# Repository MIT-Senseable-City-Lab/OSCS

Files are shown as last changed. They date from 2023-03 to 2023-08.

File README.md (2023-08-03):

# FLATBURN: the open source city scanner

[Project website](https://senseable.mit.edu/flatburn).

### Flatburn Overview
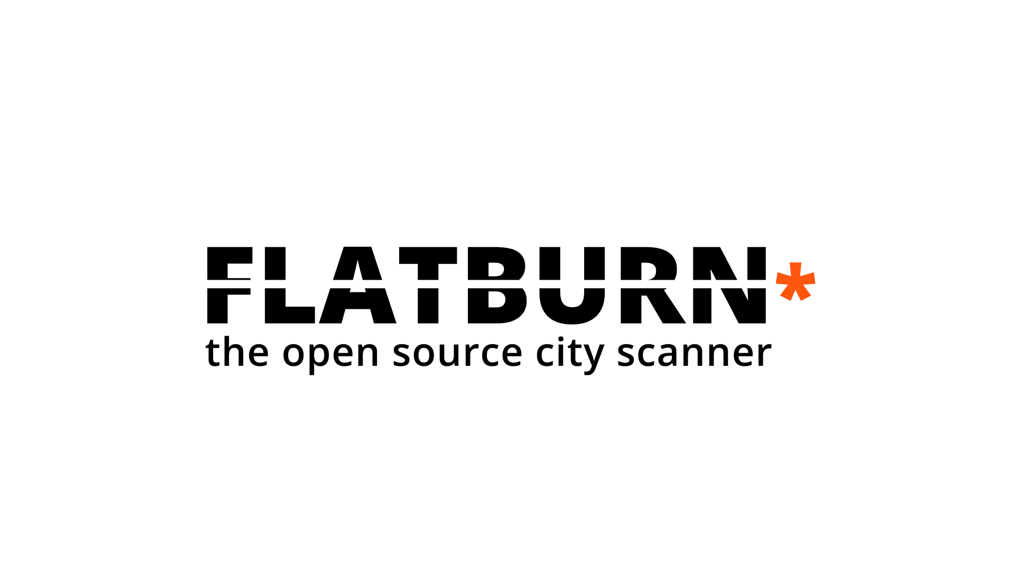
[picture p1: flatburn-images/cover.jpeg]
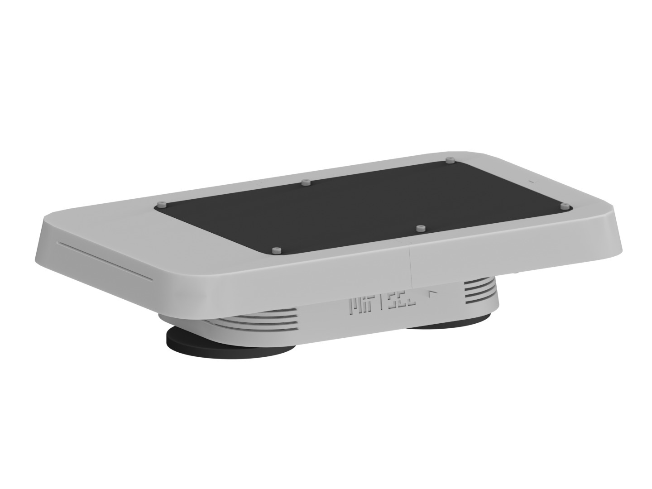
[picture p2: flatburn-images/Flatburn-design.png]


Part of the [City Scanner](https://senseable.mit.edu/cityscanner/) project at [MIT Senseable City Lab](https://senseable.mit.edu), Flatburn is an open-source, solar-powered, modular sensing platform that can be easily deployed on road vehicles to collect various environmental data. 

This repository contains all information to [build](https://github.com/MIT-Senseable-City-Lab/OSCS/tree/main/Build) your own Flatburn, [explore](https://github.com/MIT-Senseable-City-Lab/OSCS/tree/main/Explore) datasets collected using Flatburn and other City Scanner deployments worldwide and [learn](https://github.com/MIT-Senseable-City-Lab/OSCS/tree/main/Learn) how to perform environmental analysis and use the data to contribute to the development of healtier cities.

## Build
 - [/hardware](Build/Hardware)  
    - [fabrication files](Build/Hardware/Hardware%20enclosure) for Flatburn mechanical parts, including files for [3D printing](Build/Hardware/Hardware%20enclosure/To%20Print), [laser cutting](Build/Hardware/Hardware%20enclosure/To%20lasercut), and a [CAD model](Build/Hardware/Hardware%20enclosure/Flatburn_assembly.step) of the full assembly. A [bill of materials](https://docs.google.com/spreadsheets/d/1qiVyINNuo0XEu6MasEJE_p4onlJh241j/edit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) listing all the required mechanical components is also included.
    - [hardware schematics](Build/Hardware/Hardware%20schematics) contains `.brb` files for the main-board and the sensor-board which can be viewed using the [Cadence](https://www.cadence.com/en_US/home/tools/pcb-design-and-analysis/allegro-downloads-start.html) free viewer, schematics of the PCB in `.pdf` format, and a [bill of materials](https://docs.google.com/spreadsheets/d/1-UVIJEneydIf8kLRng4QxvzjM4k2ZoDa/edit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) for the electronics components.
 - [/firmware](Build/Firmware): The Flatburn main firmware code base, developed using [Particle.io](https://www.particle.io/workbench/) workbench.
 - [/fabrication handbook](Build/Handbook): The assembly guide with detailed instructions on how to build flatburn.

## Explore
- [/datasets](Explore/Datasets): `.csv` calibrated air quality datasets collected during City Scanner deployments worldwide. 
- [/calibration handbook](Explore/Calibration%20Handbook): a guide for validation and calibration of the data collected by Flatburn.

## Learn
- [/coding exercise](Learn/Coding%20Exercise): [jupyter](https://jupyter.org/) notebooks for a Python coding activity to introduce non-experts to air quality and environmental sensing and analysis methods. The activity includes exploring time series analysis, geospatial analysis, and pollution hotspot analysis. The conding activity can be used with the [datasets](Explore/Datasets) captured by previous City Scanner deployment as well as data captured by Flatburn.
- [/facilitator handbook](Learn/Facilitator%20Handbook): a facilitator guide and educational slides to implement the coding exercise as part of workshops or classroom activities.

All materials are released under [MIT license](LICENSE).

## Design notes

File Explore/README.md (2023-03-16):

# EXPLORE OSCS
The Explore folder contains two sections:
- [/datasets](https://github.com/MIT-Senseable-City-Lab/OSCS/tree/main/Explore/Datasets): The folder contains `.csv` Calibrated air quality data of City Scanner. 
- [/data collection document](https://github.com/MIT-Senseable-City-Lab/OSCS/tree/main/Explore/Calibration%20Handbook): Open-source manual and code for data collection

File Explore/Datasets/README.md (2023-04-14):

# Open City Scanner Data
This folder contains open City Scanner data sets collected in four deployments in three cities. Raw sensor readings were collected and calibrated following standardized air sensor performance evaluation guidelines recommended by the U.S. EPA. The general method is presented in the following diagram and details can be found in the open source [calibration handbook](https://github.com/MIT-Senseable-City-Lab/OSCS/blob/main/Explore/Calibration%20Handbook/Calibration%20Handbook.pdf).



Figure. Data post-processing and validation protocols

Detailed information about the deployments and data files is included in he following table. In total, there are eight data files. Given that the second pilot in NYC contains a huge amount of data, its full dataset is divided into five sections. A [data descriptor](https://github.com/MIT-Senseable-City-Lab/OSCS/blob/main/Explore/Datasets/OSCS_OpenDataSupplement.pdf) is also included. 

Table. Deployments and open data sets
|City|Sensing target pollutants|Sensing fleet|Duration|
|----|---|---|---|
|New York City, US|Particulate matter, particle size distribution, NO2|Five municipal vehicles|Jan. 2020 - Feb. 2020; Sep. 2021 - Dec. 2021|
|Boston, US|Particulate matter, particle size distribution, NO2|One mobile air laboratory|Feb. 2022 - Apr. 2022|
|Beirut, Lebanon|Particulate matter, particle size distribution|Two taxis|Feb. 2022 - Jun. 2022|

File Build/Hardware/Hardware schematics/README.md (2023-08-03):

Files for Electronic production

A BoM (bill of materials) listing all the required parts and components to build a Flatburn hardware can be found [here](https://docs.google.com/spreadsheets/d/1-UVIJEneydIf8kLRng4QxvzjM4k2ZoDa/edit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)

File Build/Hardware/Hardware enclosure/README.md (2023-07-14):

Files for 3D printing, laser-cutting and the full CAD assembly.

A BoM (bill of materials) listing all the required parts and components to build a Flatburn enclosure is available [here](https://docs.google.com/spreadsheets/d/1qiVyINNuo0XEu6MasEJE_p4onlJh241j/edit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).

**Process pictures showing the main assembly steps:**



Our prototypes were printed on a Flashforge Guider ii, but the files can be printed on most standard desktop 3D printers (e.g. Prusa i3, Ender 3, Ultimaker etc). 

We suggest the following settings:

* Infill type: Triangular or Esagonal 
* Infill Percentage: at leat 50% 
* Layer height: this depend on the printer nozzle, I would go with the pre-defined setting.

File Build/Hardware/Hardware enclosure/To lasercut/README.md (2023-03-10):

Vector `.dxf` files for lasercutting of the enclosure 'base-plate' and 'in-between plate' (dimensions in mm). Suggested material is acrylic with the relevant material thickness specified in the name (closest available metric values can also be substituted :) ). The 'in-between' plate may alternatively also be [3D printed](https://github.com/MIT-Senseable-City-Lab/OSCS/tree/main/Build/Hardware/Hardware%20enclosure/To%20Print).

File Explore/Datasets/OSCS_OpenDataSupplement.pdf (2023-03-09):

## City Scanner Open Data Supplement

This document provides expanded definitions, units, and more information on the data provided in the .CSV files from City Scanner deployments.

### Data Fields

time

- The time field is in Unix time and can be converted to local time with a simple script or using online tools.

latitude, longitude

- The latitude and longitude readings from the devices are determined via GPS and given in degrees for projected corrdinates.

pm1, pm25, pm10

- The particulate matter (pm) readings from the optical particle counter after calibration.
- The units for each are instantaneous mass concentrations in µg/m³

no2

- The nitrogen dioxide (no2) readings from the gas sensors after conversion and calibration.
- The unit is instantaneous concentrations in parts per billion (ppb).

bin0-bin23

- Twenty-four bins from the OPC containing particle number counts for different sizes, ranging from 0.35 to 40 µm. The bin boundary sizes are as follows from bin0 to bin23:
- 0.35
- 0.46
- 0.66
- 1.0
- 1.3
- 1.7
- 2.3
- 3.0
- 4.0
- 5.2
- 6.5

- 8.0
- 10.0
- 12.0
- 14.0
- 16.0
- 18.0
- 20.0
- 22.0
- 25.0
- 28.0
- 31.0
- 34.0
- 37.0
- 40.0

temperature

- Ambient temperature reading in degrees Celsius.

humidity

- Ambient relative humidity reading in percentage

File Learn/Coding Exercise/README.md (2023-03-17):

This folder contains a coding activity written in Python to introduce users to air quality and environmental sensing methods
by working with CityScanner Data, exploring time series analysis, geospatial analysis, and pollution hotspot analysis.
There are 2 versions: 
- One is a `.ipynb` file containing python code and some descriptive text, which can be run in an environment of your choosing.
- The other is a `.ipynb` file intended to be run on the [Google CoLab](https://colab.research.google.com/) platform. 

The notebooks provide sample code to run with New York City Deployment data, which can be edited to use different data files we provide in [explore/datasets](/Explore/Datasets).

Please refer to the [facilitator handbook](/Learn/Facilitator%20Handbook) for further instructions.

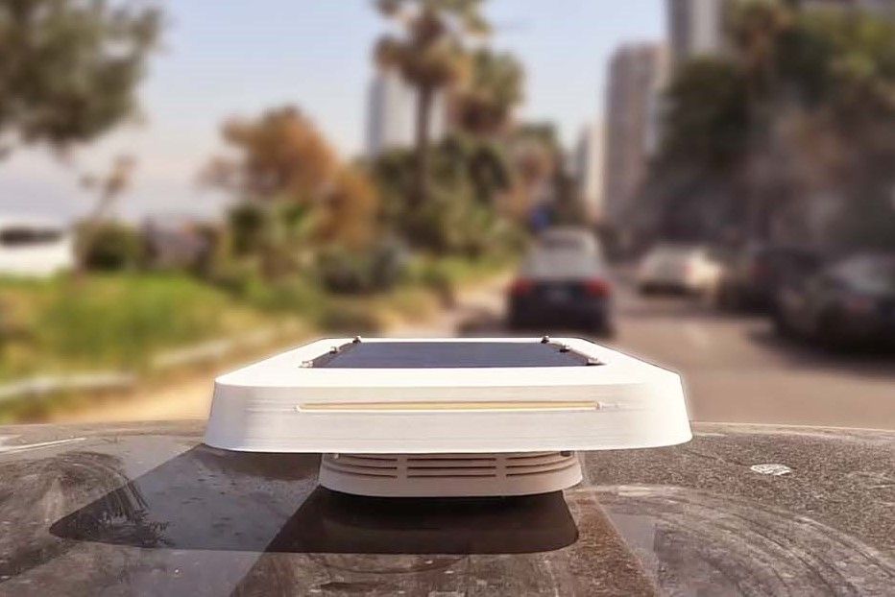
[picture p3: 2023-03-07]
flatburn-images/Flatburn.jpeg

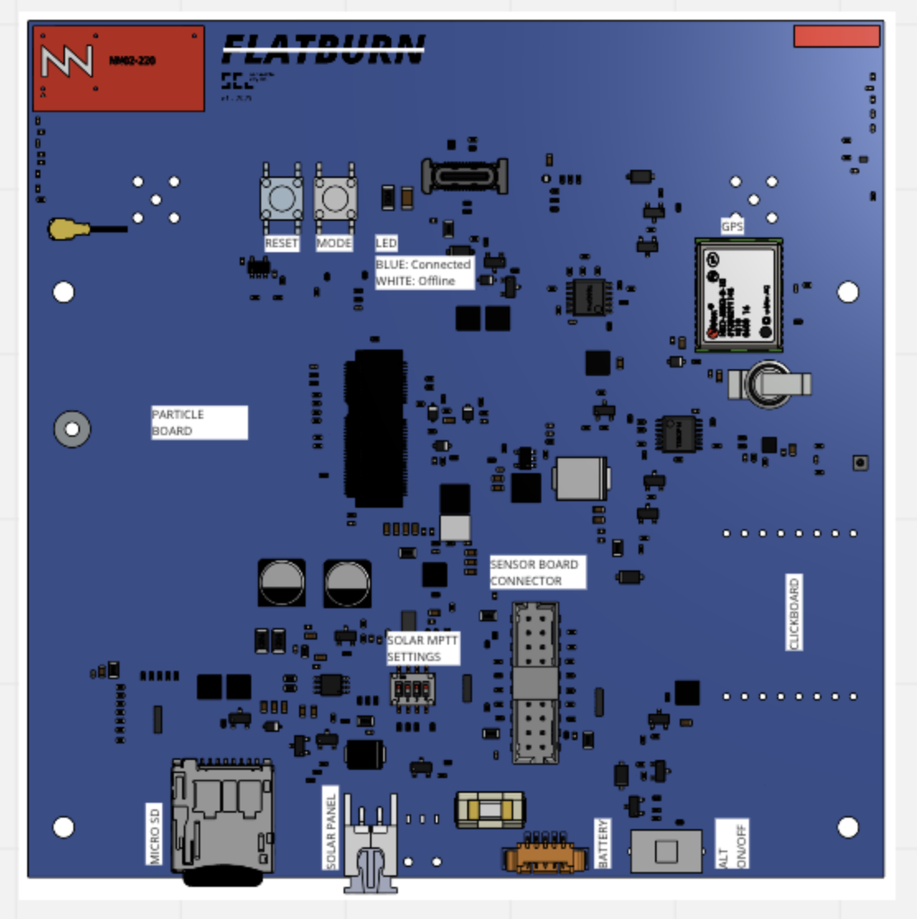
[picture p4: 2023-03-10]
flatburn-images/Mainboard.png

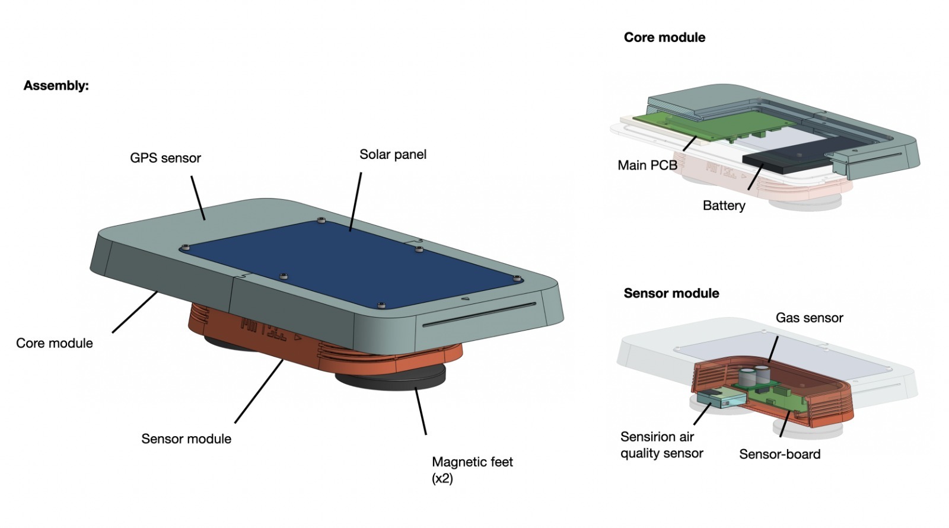
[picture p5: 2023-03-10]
flatburn-images/flatburn configuration.jpeg

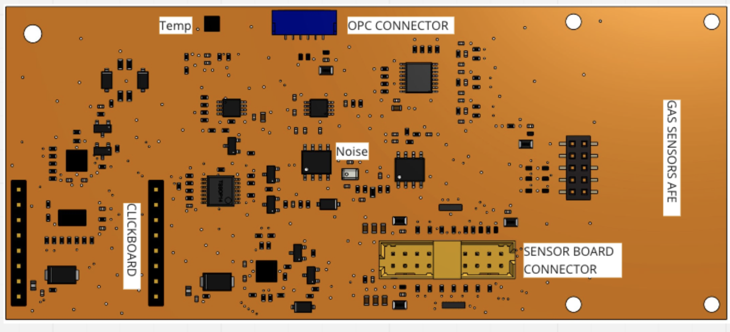
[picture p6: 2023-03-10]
flatburn-images/Sensorboard.png

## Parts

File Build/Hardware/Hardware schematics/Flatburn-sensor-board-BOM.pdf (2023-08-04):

Item | Quantity | Reference | Part | MPN | MPN2 | Description | Temperature | Distributor | Type | Package | Database
1 | 1 | CS1 | CS V2 2L 35um | | | C.S. CS SENSOR V2 (115x52)mm HAL 2L/SO/SR sp=1.6mm Cu=35um | TG140 | WE-ONLINE
2 | 36 | C9,C10,C11,C15,C16,C17,C18,C19,C20,C27,C28 ,C99,C102,C103,C104,C105,C106,C108,C109,C1 10,C111,C112,C113,C114,C115,C116,C117,C123 ,C124,C125,C126,C128,C129,C130,C132,C133 | 100n/50V | | | CHIP CAP.CER. 100nF 50V 10% X7R 0402 | -55..+125 | | SMD | CS-C-0402
3 | 8 | C21,C22,C23,C24,C25,C26,C107,C134 | 10u/10V-X5R | | | CHIP CAP.CER. 10uF 10V 10% X5R 0603 | | FAE | SMD | CS-C-0603 | 28168
4 | 4 | C121,C122,C127,C131 | 1u/16V-X5R | | | CHIP CAP.CER. 1uF 16V 10% X5R 0402 | | FAE | SMD | CS-C-0402 | 37485
5 | 2 | DZ3,DZ5 | MMSZ5226BT1G | MMSZ5226BT1G | | DIODO ZENER 0.5W 3.3V MMSZ5226BT1G ONSEMI SOD123 SMT | | M-863-MMSZ5226BT1G | SMD | SOD123
6 | 2 | DZ4,DZ7 | MMSZ5221BT1G | MMSZ5221BT1G | | DIODO ZENER 0.5W 2.4V MMSZ5221BT1G ONSEMI SOD123 SMT | -55°C .. +150°C | M-863-MMSZ5221BT1G | SMD | SOD123
7 | 2 | F2,F3 | 0ZCM0020FF2G | 0ZCM0020FF2G | | FUSIBILE RIPRIST. 0.2A 9V 0603 0ZCM0020FF2G BEL FUSE SMT | -40°..+85° | FAE | SMD | FS-0603 | 40877
8 | 1 | J7 | 878322014 | 878322014 | | HEADER 20P M DOPPIA FILA P=2.00 878322014 MOLEX SMD | -55..105 | M-538-87832-2014 | SMD | J-10X2-0200-MDS-878322014
9 | 2 | J9,J10 | STRIP 8P - FDT | | | STRIP 1P F/D P=2.54 H=7 NERA 801-87-036-1001 | | FAE | THT | J-8-0254-FDT | 1692
10 | 1 | J11 | BF100-10-A-D-1-0640-L-C | BF100-10-A-D-1-0640-L-C | | CONN. F-C 10P F/D P=2 BF100-10-A-D-1-0640-L-C GCT SMT | | D-2073-BF100-10-A-D-1-0640-L-CCT-ND | SMD | J-5X2-0200-FDS-BF100
11 | 1 | J12 | SM06B-GHS-TB | SM06B-GHS-TB | | CONN. GH 6P M/O P=1.25 GH JST SM06B-GHS-TB(LF)(SN) | -25°..+85° | D-455-1568-1-ND | SMD | J-6-0125-MOS-SM06B-GHS-TB
12 | 1 | J13 | S5B-ZR-SM4A-TF | S5B-ZR-SM4A-TF | | CONN. ZH 5P M/O P=1.5 ZH JST S5B-ZR-SM4A-TF | -25°..+85° | D-455-1696-1-ND | SMD | J-5-0150-MOS-S5B-ZR-SM4A
13 | 5 | L3,L5,L6,L7,L8 | BLM21PG221SN1D | BLM21PG221SN1D | | FILTRO 220R 2A 25% 0805 BLM21PG221SN1D MURATA SMT | -55°..+125° | FAE | SMD | LS-0805 | 20590
14 | 3 | Q11,Q24,Q26 | BSS84 | | | TRANSISTOR MOSFET P BSS84,215 SOT-23 SMT | -55°..+150° | FAE | SMD | SOT23 | 28241
15 | 3 | Q12,Q25,Q27 | BC817-25 | | | TRANSISTOR NPN BC817-25 SOT-23 SMT | | FAE | SMD | SOT23 | 15414
16 | 1 | Q28 | BSS138 | | | TRANSISTOR MOSFET N BSS138 SOT-23 SMT | | FAE | SMD | SOT23 | 17269
17 | 29 | R18,R19,R20,R21,R22,R23,R24,R25,R26,R27,R2 8,R29,R32,R36,R40,R41,R42,R43,R44,R45,R46, R47,R50,R96,R97,R101,R102,R226,R231 | 33R | | | CHIP RES. 33R 0402 1/16W 1% 100PPM/°C | | FAE | SMD | RS-0402 | 38764
18 | 2 | R34,R48 | 0R | | | CHIP RES. 0R 0603 1/16W 1% | -55°..+150° | FAE | SMD | RS-0603 | 15541
19 | 5 | R35,R61,R62,R249,R288 | 0R | | | CHIP RES. 0R 0402 1/16W 1% | | FAE | SMD | RS-0402 | 25681
20 | 15 | R37,R57,R232,R236,R239,R240,R241,R242,R24 4,R246,R270,R271,R276,R289,R290 | 100k | | | CHIP RES. 100K 0402 1/16W 1% | | FAE | SMD | RS-0402 | 25127
21 | 4 | R51,R234,R245,R282 | 1k | | | CHIP RES. 1K 0402 1/16W 1% | -55°..+155° | FAE | SMD | RS-0402 | 25126
22 | 6 | R53,R54,R105,R225,R230,R280 | 100R | | | CHIP RES. 100R 0402 1/16W 1% | | FAE | SMD | RS-0402 | 26315
23 | 22 | R59,R60,R106,R233,R235,R237,R238,R247,R25 2,R253,R256,R257,R258,R263,R264,R265,R266, R272,R274,R278,R281,R284 | 10k | | | CHIP RES. 10K 0402 1/16W 1% | -55°..+125° | FAE | SMD | RS-0402 | 25129
24 | 6 | R254,R255,R259,R260,R261,R262 | 5.1k | | | CHIP RES. 5K1 0402 1/16W 1% | -55°..+155° | FAE | SMD | RS-0402 | 46041
25 | 2 | R267,R268 | 1M | | | CHIP RES. 1M 0402 1/16W 1% | | FAE | SMD | RS-0402 | 32464
26 | 1 | R269 | 390R | | | CHIP RES. 390R 0603 1/16W 1% | | FAE | SMD | RS-0603 | 20433
27 | 2 | R273,R275 | 120k | RC0402FR-07120KL | | CHIP RES. 120k 0402 1/16W 1% 100PPM/C | | | SMD | RS-0402
28 | 1 | R283 | 2.2k | | | CHIP RES. 2K2 0402 1/16W 1% | | FAE | SMD | RS-0402 | 35095
29 | 2 | TVS7,TVS11 | D3V3F8U9LP3810-7 | | | INTEGRATO SIGNAL PROTECTION D3V3F8U9LP3810-7 DIODES UDFN3810-9 SMT | -55°..+85° | M-621-D3V3F8U9LP3810-7 | SMD | UDFN3810-9
30 | 13 | TVS8,TVS9,TVS10,TVS13,TVS14,TVS15,TVS16 ,TVS17,TVS18,TVS19,TVS20,TVS21,TVS22 | NSPU3051N2T5G | | | DIODO TVS TRANSIL UNIDIR. 5.5V NSPU3051N2T5G X2DFN SMT | -65°..+150° | D-NSPU3051N2T5GOSC T-ND | SMD | D-XDFN2
31 | 2 | U1,U3 | TXS0104ERGYR | TXS0104ERGYR | | INTEGRATO TXS0104ERGYR TEXAS VQFN14 SMT | -40°C..85°C | FAE | SMD | VFQFN14-EXP-0350X0350 | 41323
32 | 1 | U2 | TXS0108ERGYR | TXS0108ERGYR | | INTEGRATO TXS0108ERGYR TI VQFN20 SMT | -40°..85° | D-296-24806-1-ND | SMD | VFQFN20-EXP-0350X0450
33 | 1 | U15 | 74LV4066PW | 74LV4066PW | | INTEGRATO SWITCH 74LV4066PW NXP TSSOP14 SMT | -40°C..125°C | M-771-LV4066PW118 | SMD | TSSOP14
34 | 1 | U16 | BME280 | BME280 | | INTEGRATO BME280 BOSCH LGA8 SMT | -40°..+85° | FAE | SMD | IC-BME280 | 38357
35 | 1 | U17 | ADS7828E | ADS7828E | ADS7828EB | INTEGRATO ADC/DAC ADS7828E TEXAS TSSOP16 SMT | -40°..+85° | FAE | SMD | TSSOP16 | 26248
36 | 1 | U18 | CMM-2718AT-42316-TR | CMM-2718AT-42316-TR | | MICROPHONE MEMS CUI DEVICES SMT | -40°..+100° | M-490-CMM2718AT42316TR | SMD | lga4-0275x0185
37 | 1 | U19 | LTC1966IMS8 | LTC1966IMS8#PBF | | INTEGRATO RMS-TO-DC LTC1966 LINEAR MSOP8 SMT | -40°..+85° | M-584-LTC1966IMS8#PBF | SMD | MSOP8
38 | 2 | U20,U21 | MCP6022-I/SN | MCP6022-I/SN | | INTEGRATO SIGNAL AMPLIFIER MCP6022-I/SN MICROCHIP SOIC-8 SMT | -40°..+85° | M-579-MCP6022-I/SN | SMD | SOIC8
39 | 1 | U22 | MAX5805BAUB+T | MAX5805BAUB+T | | INTEGRATO DAC MAX5805BAUB+ MAXIM MSOP10 SMT | -40°..+125° | M-700-MAX5805BAUB+T | SMD | MSOP10
194 | 17

# MECHANICAL

1 | 1 | ASS1 | SEN55-SDN-T | SEN55-SDN-T | SENSORE PM SEN55-SDN-T SENSIRION | -10°..50° | M-403-SEN55-SDN-T | THT
2 | 1 | ASS2 | 810-0021-01 | 810-0021-01 | SENSORE NO2/O3/NO 810-0021-01 ALPHASENSE | -10°..50° | | THT
2 | 2

# NOT MOUNTED

1 | 1 | ASS3 | NU | SPS30 | SENSORE PM SPS30 SENSIRION | -10°..60° | M-403-SPS30 | THT
2 | 1 | C14 | NU | | CHIP CAP.CER. 1nF 50V 10% X7R 0402 | | FAE | SMD | CS-C-0402 | 33357
3 | 2 | C100,C101 | NU | | CHIP CAP.CER. 100nF 50V 10% X7R 0402 | -55..+125 | | SMD | CS-C-0402
4 | 2 | DS5,DS6 | NU | SS14 | DIODO SCHOTTKY 1A 40V SS14 SMA SMT | | FAE | SMD | SMA | 16655
5 | 3 | FID1,FID2,FID3 | TPS | | FIDUCIAL | | FAE | SMD | FIDUCIAL
6 | 2 | R33,R49 | NU | | CHIP RES. 0R 0603 1/16W 1% | -55°..+150° | FAE | SMD | RS-0603 | 15541
7 | 5 | R38,R228,R243,R286,R287 | NU | | CHIP RES. 0R 0402 1/16W 1% | | FAE | SMD | RS-0402 | 25681
8 | 1 | R39 | NU | | CHIP RES. 33R 0402 1/16W 1% 100PPM/°C | | FAE | SMD | RS-0402 | 38764
9 | 5 | R248,R250,R251,R277,R285 | NU | | CHIP RES. 10K 0402 1/16W 1% | -55°..+125° | FAE | SMD | RS-0402 | 25129
CUSTOMER | MIT
PROJECT | 2022-0630 (CITYSCANNER-EVO-SENSOR)
REVISION | 2
SCHEMATIC | 20220630_CITYSCANNER-EVO-SENSOR_V2
DATA | 23/05/2023
DRAFTED | M.
APPROVED | Nome Approved

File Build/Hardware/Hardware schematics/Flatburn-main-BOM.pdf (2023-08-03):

Item | Quantity | Reference | Part | MPN | Description | Temperature | Distributor | Type | Package | Database
1 | 1 | ANT1 | NN02-220 | NN02-220 | ANTENNA CHIP LTE D=24X12X2 NN02-220 IGNION SMT | -40°..+125° | M-128-NN02-220 | SMD | ANT-NN02-220
2 | 1 | ANT2 | NN02-224 | NN02-224 | ANTENNA CHIP GNSS D=12X3X2.4 NN02-224 IGNION SMT | -40°..+125° | M-128-NN02-224 | SMD | ANT-NN02-224
3 | 1 | CS1 | CS V3 4L 35um | | C.S. CS-EVO V3 (120x120)mm HAL 4L/SO/SR sp=1.6mm Cu=35um | TG140 | WE-ONLINE
4 | 36 | C1,C7,C9,C10,C11,C24,C26,C27,C28,C30,C36,C4 4,C45,C46,C53,C54,C55,C62,C63,C64,C71,C73,C7 4,C75,C79,C87,C88,C90,C91,C93,C96,C99,C101,C 103,C105,C106 | 100n/50V | | CHIP CAP.CER. 100nF 50V 10% X7R 0402 | -55..+125 | | SMD | CS-C-0402
5 | 19 | C2,C25,C32,C41,C42,C43,C47,C48,C49,C50,C51, C52,C56,C57,C60,C61,C78,C80,C89 | 10u/10V-X5R | | CHIP CAP.CER. 10uF 10V 10% X5R 0603 | | FAE | SMD | CS-C-0603 | 28168
6 | 1 | C4 | 100k | | CHIP RES. 100K 0603 1/16W 1% | | FAE | SMD | RS-0603 | 20648
7 | 1 | C6 | 10n/1kV | | CHIP CAP.CER. 10nF 1000V 10% X7R 1206 | | FAE | SMD | CS-C-1206 | 28470
8 | 1 | C8 | 10n/50V | | CHIP CAP.CER. 10nF 50V 10% X7R 0402 | | FAE | SMD | CS-C-0402 | 21365
9 | 2 | C21,C23 | 220u/16V | | CHIP CAP.ELETTR. 220uF 16V 20% CASE D=6.3x8 | | FAE | SMD | CS-E-D | 15190
10 | 6 | C31,C34,C35,C72,C86,C97 | 1u/16V | | CHIP CAP.CER. 1uF 16V 10% X7R 0603 | | FAE | SMD | CS-C-0603 | 20891
11 | 1 | C38 | 22p/50V-NP0 | | CHIP CAP.CER. 22pF 50V 5% NPO 0402 | | FAE | SMD | CS-C-0402 | 27826
12 | 2 | C39,C40 | 330p/50V-C0G | | CHIP CAP.CER. 330pF 50V 5% NPO 0402 | -55°..+125° | FAE | SMD | CS-C-0402 | 25119
13 | 1 | C81 | 2.4p/100V-C0G | GJM1555C1H2R4WB01D | CHIP CAP.CER. 2.4pF 100V 0.1pF C0G 0402 GJM1555C1H2R4WB01D SMT | -55°..+125° | FAE | SMD | CS-C-0402 | 29699
14 | 1 | C82 | 1.2p/50V-C0G | GJM1555C1H1R2WB01 | CHIP CAP.CER. 1.2pF 50V +-0.05pF C0G 0402 | -55°..+125° | FAE | SMD | CS-C-0402
15 | 1 | C83 | 0.4p/50V-C0G | GJM1555C1HR40WB01 | CHIP CAP.CER. 0.4pF 50V +-0.05pF C0G 0402 | -55°..+125° | FAE | SMD | CS-C-0402 | 42804
16 | 1 | C85 | 330mF/3.3V | DSK-3R3H334T-HL | COND. SUPERCAP 330mF 3.3V -20% /+80% DSK-3R3H334T-HL D=6.8x6.8 SMT | -10°..+60° | FAE | SMD | CS-SCAP-DSK | 48722
17 | 1 | C102 | 1n/50V | | CHIP CAP.CER. 1nF 50V 10% X7R 0402 | | FAE | SMD | CS-C-0402 | 33357
18 | 1 | C104 | 0.9p/50V-C0G | GJM1555C1HR90WB01D | CHIP CAP.CER. 0.9pF 50V +-0.05pF C0G 0402 GJM1555C1HR90WB01D MURATA SMT | -55°..+125° | FAE | SMD | CS-C-0402
19 | 1 | DSW1 | DIP-SW-MCDHN-04F-T-V | | DIP SWITCH 4P/D NERO MCDHN-04F-V MULTICOMP SMT | | FAE | SMD | DSS-4-0127-MCDHN | 31346
20 | 6 | DS2,DS4,DS8,DS9,DS10,DS11 | BAT54J | BAT54J,115 | DIODO SCHOTTKY 0.3A 40V BAT54J SOD-323 SMT | | FAE | SMD | SOD323 | 34244
21 | 1 | DS7 | SS34 | SS34 | DIODO SCHOTTKY 3A 40V SS34 DO-214AB SMT | -55°..+125° | FAE | SMD | SMC | 25363
22 | 2 | DZ2,DZ5 | MMSZ5226BT1G | MMSZ5226BT1G | DIODO ZENER 0.5W 3.3V MMSZ5226BT1G ONSEMI SOD123 SMT | | M-863-MMSZ5226BT1G | SMD | SOD123
23 | 2 | DZ6,DZ7 | MMSZ5221BT1G | MMSZ5221BT1G | DIODO ZENER 0.5W 2.4V MMSZ5221BT1G ONSEMI SOD123 SMT | -55°C .. +150°C | M-863-MMSZ5221BT1G | SMD | SOD123
24 | 1 | F1 | 0154005-DR | 0154005.DR | FUS.+PORTAFUS. 5A RAPIDO. 0154005.DR LITTELFUSE SMT | -55°..+125° | FAE | SMD | F-LT154 | 39312
25 | 1 | J2 | 54-00125 | 54-00125 | PRESA JACK DC 3.5-1.1 - TENSILITY - 54-00125 | -25°C - +85°C | D-839-1508-ND | THT | J-54-00125
26 | 1 | J5 | 53261-0571 | 0532610571 | CONN. PICOBLADE 5P M/90° P=1.25 53261-0571 MOLEX SMT | | FAE | SMD | J-5-0125-MOS-PICOBLADE | 24686
27 | 1 | J6 | DX07S024WJ3R400 | DX07S024WJ3R400 | CONN. USB 3.0 F/D TIPO C C.S. DX07S024WJ3R400 JAE ELECTRONICS | -30°..+80° | FAE | SMD | J-24-0050-FDS-USBC-DX07 | 45706
28 | 1 | J7 | 878322014 | 878322014 | HEADER 20P M DOPPIA FILA P=2.00 878322014 MOLEX SMD | -55..105 | M-538-87832-2014 | SMD | J-10X2-0200-MDS-878322014
29 | 1 | J12 | MDT420E01001 | MDT420E01001 | CONN. M.2 75P M/90° P=0.5 MDT420E01001 AMPHENOL SMT | -40°..+80° | FAE | SMD | J-75-0050-MOS-M2-E | 44633
30 | 1 | J13 | uSD - 502774-0891 | 5027740891 | CONN. MICROSD 8P F/90° PUSH-PUSH 502774-0891 MOLEX SMT | -25°..+85° | FAE | SMD | J-8-0110-FOS-SD-M502774 | 39314
31 | 1 | J15 | uFL-R-SMT-1-10 | U.FL-R-SMT-1(10) | CONN. RF M U.FL-R-SMT-1(10) HIROSE SMT | -40°..+90° | FAE | SMD | J-3-MDS-UFL | 28096
32 | 1 | LD1 | GENERICO | | DIODO LED ROSSO 0603 SMT | | FAE | SMD | LD-0603 | 15407
33 | 1 | LD2 | SML-LX0404SIUPGUSB | SML-LX0404SIUPGUSB | DIODO LED RGB SML-LX0404SIUPGUSB LUMEX SMT | | FAE | SMD | LD-0404-SMLLX | 37708
34 | 6 | L1,L2,L3,L5,L6,L9 | BLM21PG221SN1D | BLM21PG221SN1D | FILTRO 220R 2A 25% 0805 BLM21PG221SN1D MURATA SMT | -55°..+125° | FAE | SMD | LS-0805 | 20590
35 | 1 | L7 | XAL4030-682ME | XAL4030-682ME | INDUTTANZA 6.8 uH 3.9A 20% 4X4 XAL4030-682ME COILCRAFT SMT | -40°..+125° | M-994-XAL4030-682MEB | SMD | LS-XAL40
36 | 1 | L8 | XAL4020-102MEB | XAL4020-102MEB | INDUTTANZA 1uH 8.7A 20% D=4.3x4.3 XAL4020-102ME COILCRAFT SMT | -40°..+125° | M-994-XAL4020-102MEB | SMD | LS-XAL40
37 | 1 | L10 | LQW15AN1N3C80D | LQW15AN2N3G80D | INDUTTANZA 1.3nH 3.15A +-0.2nH 0402 LQW15AN2N3G80D MURATA SMT | -55°..+125° | | SMD | LS-0402
38 | 16 | R2,R8,L11,R102,R128,R131,R132,R134,R139,R14 1,R149,R179,R184,R224,R251,R252 | 0R | | CHIP RES. 0R 0402 1/16W 1% | | FAE | SMD | RS-0402 | 25681
39 | 1 | L12 | LQW18AN8N7G80D | LQW18AN8N7G80D | INDUTTANZA 8.7nH 1.6A 2% 0603 LQW18AN8N7G80D MURATA SMT | -55°..+125° | | SMD | LS-0603
40 | 1 | L13 | LQW15AN14NG80D | LQW15AN14NG80D | INDUTTANZA 14nH 1.15A 2% A FILO 0402 SMT | -55°..+125° | M-81-LQW15AN14NG80D | SMD | LS-0402
41 | 1 | L14 | LQW18AN7N2G80D | LQW18AN7N2G80D | INDUTTANZA 7.2nH 1.9A 2% 0603 LQW18AN7N2G80D MURATA SMT | -55°..+125° | | SMD | LS-0603
42 | 1 | L16 | LQW18AN6N0G80D | LQW18AN6N0G80D | INDUTTANZA 6nH 1.9A 2% 0603 LQW18AN6N0G80D MURATA SMT | -55°..+125° | | SMD | LS-0603
43 | 1 | L17 | LQW15AN7N5H00D | LQW15AN7N5H00D | INDUTTANZA 7.5nH 0.57A 3% A FILO 0402 LQW15AN7N5H00D MURATA SMT | -55°..+125° | FAE | SMD | LS-0402 | 43079
44 | 1 | L18 | LQW15AN3N9G80D | LQW15AN3N9G80D | INDUTTANZA 3.9nH 1.95A 2% 0402 LQW15AN3N9G80D MURATA SMT | -55°..+125° | | SMD | LS-0402
45 | 1 | L19 | LQW18AN36NG80D | LQW18AN36NG80D | INDUTTANZA 36nH 0.91A 2% 0603 LQW18AN36NG80D MURATA SMT | -55°..+125° | | SMD | LS-0603
46 | 1 | L20 | LQW18AN33NG80D | LQW18AN33NG80D | INDUTTANZA 33nH 1.1A 2% 0603 LQW18AN33NG80D MURATA SMT | -55°..+125° | | SMD | LS-0603
47 | 1 | L21 | LQW15AN1N3C80D | LQW15AN1N3C80D | INDUTTANZA 1.3nH 3.15A +-0.2nH 0402 LQW15AN1N3C80D MURATA SMT | -55°..+125° | | SMD | LS-0402
48 | 1 | MOD1 | NEO-M8U-06B | NEO-M8U-06B | MODULO GPS NEO-M8U-06B U-BLOX SMT | -40°..+85° | FAE | SMD | MOD-NEO-M8U | 50104
49 | 2 | PB1,PB2 | FSM14JSMAS | | TASTO 24V 0.05A 6X6 SPST FSM14JSMAS TE SMT | -40..+85 | D-450-2161-ND | SMD | PB-FSM14JS
50 | 7 | Q1,Q2,Q6,Q7,Q13,Q17,Q18 | SISS27DN-T1-GE3 | | TRANSISTOR MOSFET P SISS27DN-T1-GE3 POWERPACK-1212-8S SMT | -65°..+150° | FAE | SMD | POWERVDFN8-0330X0330 | 41716
51 | 7 | Q3,Q4,Q9,Q10,Q15,Q23,Q25 | BC817-25 | | TRANSISTOR NPN BC817-25 SOT-23 SMT | | FAE | SMD | SOT23 | 15414
52 | 5 | Q5,Q14,Q16,Q19,Q20 | BSS138 | | TRANSISTOR MOSFET N BSS138 SOT-23 SMT | | FAE | SMD | SOT23 | 17269
53 | 3 | Q8,Q22,Q24 | BSS84 | | TRANSISTOR MOSFET P BSS84,215 SOT-23 SMT | -55°..+150° | FAE | SMD | SOT23 | 28241
54 | 36 | R1,R7,R17,R64,R90,R94,R108,R109,R116,R118,R 119,R120,R123,R133,R143,R145,R146,R153,R154 ,R171,R172,R173,R181,R183,R185,R186,R187,R1 88,R208,R213,R216,R217,R219,R232,R236,R243 | 100k | | CHIP RES. 100K 0402 1/16W 1% | | FAE | SMD | RS-0402 | 25127
55 | 21 | R3,R10,R63,R65,R71,R72,R73,R81,R105,R114,R1 15,R122,R127,R135,R144,R211,R212,R233,R235, R239,R254 | 10k | | CHIP RES. 10K 0402 1/16W 1% | -55°..+125° | FAE | SMD | RS-0402 | 25129
56 | 6 | R5,R13,R87,R210,R234,R242 | 1k | | CHIP RES. 1K 0402 1/16W 1% | -55°..+155° | FAE | SMD | RS-0402 | 25126
57 | 15 | R6,R77,R88,R89,R111,R113,R124,R125,R129,R17 7,R178,R197,R206,R225,R230 | 100R | | CHIP RES. 100R 0402 1/16W 1% | | FAE | SMD | RS-0402 | 26315
58 | 2 | R14,R16 | 5.1k | | CHIP RES. 5K1 0402 1/16W 1% | -55°..+155° | FAE | SMD | RS-0402 | 46041
59 | 1 | R15 | 1M | | CHIP RES. 1M 1206 1/4W 1% | | FAE | SMD | RS-1206 | 39104
60 | 21 | R18,R19,R20,R21,R22,R23,R24,R25,R26,R27,R28, R29,R168,R169,R170,R174,R175,R202,R209,R22 6,R231 | 33R | | CHIP RES. 33R 0402 1/16W 1% 100PPM/°C | | FAE | SMD | RS-0402 | 38764
61 | 2 | R66,R68 | 0R04 | | CHIP RES. 0R04 1206 1/4W 1% | | FAE | SMD | RS-1206 | 38917
62 | 3 | R67,R69,R136 | 470R | | CHIP RES. 470R 0402 1/16W 1% | | FAE | SMD | RS-0402 | 25128
63 | 5 | R70,R79,R82,R83,R84 | 22k | | CHIP RES. 22K 0402 1/16W 1% | | FAE | SMD | RS-0402 | 39666
64 | 3 | R74,R75,R76 | 10R | | CHIP RES. 10R 0603 1/16W 1% | | FAE | SMD | RS-0603 | 16149
65 | 1 | R85 | 330R | | CHIP RES. 330R 0402 1/16W 1% | | FAE | SMD | RS-0402 | 26311
66 | 2 | R96,R101 | 39.2k | | CHIP RES. 39K2 0402 1/16W 1% | -55°..+155° | FAE | SMD | RS-0402 | 40438
67 | 2 | R98,R99 | 0R | | CHIP RES. 0R 0805 1/8W 1% | | FAE | SMD | RS-0805 | 27410
68 | 1 | R103 | 12.4k | | CHIP RES. 12K4 0402 1/16W 1% 100PPM/°C | | FAE | SMD | RS-0402 | 33444
69 | 1 | R104 | 13k | | CHIP RES. 13K 0402 1/16W 1% | -55°..+125° | FAE | SMD | RS-0402 | 28703
70 | 3 | R121,R126,R189 | 2.2k | | CHIP RES. 2K2 0402 1/16W 1% | | FAE | SMD | RS-0402 | 35095
71 | 7 | R158,R159,R160,R161,R162,R163,R164 | 47k | | CHIP RES. 47K 0402 1/16W 1% 100PPM/°C | | FAE | SMD | RS-0402 | 33460
72 | 1 | R176 | 270R | | CHIP RES. 270R 0402 1/16W 1% | -55°..+125° | FAE | SMD | RS-0402 | 40388
73 | 2 | R256,R257 | 12k | | CHIP RES. 12K 0402 1/16W 1% | | FAE | SMD | RS-0402 | 39722
74 | 1 | SW1 | FS22ABP | FS22ABP | INTERR. SLITTA ON-ON DA C.S. DPDT FS22ABP E-SWITCH | -30°..+85° | FAE | THT | SW-FS22ABP
75 | 1 | TVS1 | SMBJ10CA | | DIODO TVS TRANSIL BIDIR. 600W 10V SMBJ10CA SMB SMT | | FAE | SMD | SMB | 24721
76 | 9 | TVS2,TVS4,TVS5,TVS8,TVS9,TVS10,TVS12,TVS1 3,TVS14 | NSPU3051N2T5G | | DIODO TVS TRANSIL UNIDIR. 5.5V NSPU3051N2T5G X2DFN SMT | -65°..+150° | D-NSPU3051N2T5GOSCT-ND | SMD | D-XDFN2
77 | 1 | TVS3 | ESDR0502NMUTBG | | INTEGRATO ESDR0502NMUTBG ONSEMI UFDFN6 SMT | -40°..+125° | FAE | SMD | UFDFN6 | 40789
78 | 3 | TVS7,TVS11,TVS15 | D3V3F8U9LP3810-7 | | INTEGRATO SIGNAL PROTECTION D3V3F8U9LP3810-7 DIODES UDFN3810-9 SMT | -55°..+85° | M-621-D3V3F8U9LP3810-7 | SMD | UDFN3810-9
79 | 1 | U3 | BQ24210DQCT | BQ24210DQCT | INTEGRATO BQ24210DQCT WSON10 TEXAS SMT | -40°..+85° | FAE | SMD | WSON10-EXP | 47785
80 | 1 | U4 | ISL28022FUZ | ISL28022FUZ-T7A | INTEGRATO ISL28022FUZ-T7A INTERSIL MSOP10 SMT | -40°..+125° | FAE | SMD | MSOP10 | 35950
81 | 1 | U5 | ISL91107IIAZ | ISL91107IIAZ | INTEGRATO DC DC CONVERTER ISL91107IIAZ RENESAS UFBGA15 SMT | -40°..+85° | M-968-ISL91107IIAZ-T7A | SMD | UFBGA15-0151X0215
82 | 1 | U6 | LMR62014XMFX | LMR62014XMFX | INTEGRATO DC/DC CONVERTER LMR62014XMFX TI SOT-23-5 SMT | -40°..+125° | M-926-LMR62014XMFXNOPB | SMD | SOT23-5
83 | 1 | U7 | TPS3823-33DBV | TPS3823-33DBV | INTEGRATO TPS3823-33DBVT SOT23-5 SMT | -40°C..85°C | FAE | SMD | SOT23-5 | 24637
84 | 2 | U11,U15 | 74LV4066PW | 74LV4066PW | INTEGRATO SWITCH 74LV4066PW NXP TSSOP14 SMT | -40°C..125°C | M-771-LV4066PW118 | SMD | TSSOP14
85 | 1 | U12 | KXTJ3-1057 | KXTJ3-1057 | INTEGRATO SENSOR KXTJ3-1057 KIONIX LGA12 SMT | -40°..+85° | M-912-KXTJ3-1057 | SMD | VFLGA12
86 | 1 | U14 | SHTC3 | SHTC3 | SENSORE DI TEMPERATURA E UMIDITA' SHTC3 SENSIRION SMT | -40°..+125° | M-403-SHTC3 | SMD | SENS-SHTC3
87 | 1 | U16 | BGA725L6E6327FTSA1 | BGA725L6E6327FTSA1 | INTEGRATO BGA725L6E6327FTSA1 INFINEON TSLP-6 SMT | -40°..+125° | FAE | SMD | XFDFN6 | 43081
319 | 27

# MECHANICAL

1 | 1 | ASS1 | B404x | B404x | SoM B404x Particle | -20°..65° | | THT
2 | 1 | ASS2 | KNOB M2.5x4-INOX | | VITE TCEI 2.5X4 ESAGONO INCASSATO A2 INOX | | FAE | THT | | 48266
3 | 1 | OBJ1 | 9774025151R | | DISTANZ. CIL. METALLO 5.1X2.5 9774025151R W.E SMT | | FAE | SMD | DIST-WASMSIM0250 | 44635
3 | 1

# NOT MOUNTED

1 | 1 | C3 | NU | | CHIP CAP.CER. 10uF 10V 10% X5R 0603 | | FAE | SMD | CS-C-0603 | 28168
2 | 19 | C5,C13,C15,C16,C17,C18,C19,C20,C22,C29,C33, C37,C58,C59,C65,C92,C95,C98,C100 | NU | | CHIP CAP.CER. 100nF 50V 10% X7R 0402 | -55..+125 | | SMD | CS-C-0402
3 | 1 | C12 | NU | | CHIP CAP.CER. 10nF 1000V 10% X7R 1206 | | FAE | SMD | CS-C-1206 | 28470
4 | 1 | C14 | NU | | CHIP CAP.CER. 1nF 50V 10% X7R 0402 | | FAE | SMD | CS-C-0402 | 33357
5 | 4 | C67,C68,C69,C70 | NU | | CHIP CAP.CER. 33pF 50V 5% C0G 0402 | | FAE | SMD | CS-C-0402 | 43360
6 | 1 | C84 | NU | | CHIP CAP.CER. 10nF 50V 10% X7R 0402 | | FAE | SMD | CS-C-0402 | 21365
7 | 1 | C94 | NU | | CHIP CAP.CER. 1uF 16V 10% X7R 0603 | | FAE | SMD | CS-C-0603 | 20891
8 | 2 | DS1,DS3 | NU | FSV1045V | DIODO SCHOTTKY 10A 45V FSV1045V TO277-3 SMT | -55°..+150° | FAE | SMD | TO277-3 | 42269
9 | 2 | DS5,DS6 | NU | SS14 | DIODO SCHOTTKY 1A 40V SS14 SMA SMT | | FAE | SMD | SMA | 16655
10 | 2 | DZ1,DZ4 | NU | MMSZ5221BT1G | DIODO ZENER 0.5W 2.4V MMSZ5221BT1G ONSEMI SOD123 SMT | -55°C .. +150°C | M-863-MMSZ5221BT1G | SMD | SOD123
11 | 1 | DZ3 | NU | MMSZ5226BT1G | DIODO ZENER 0.5W 3.3V MMSZ5226BT1G ONSEMI SOD123 SMT | | M-863-MMSZ5226BT1G | SMD | SOD123
12 | 3 | FID1,FID2,FID3 | TPS | | FIDUCIAL | | FAE | SMD | FIDUCIAL
13 | 2 | F2,F3 | NU | 0ZCM0020FF2G | FUSIBILE RIPRIST. 0.2A 9V 0603 0ZCM0020FF2G BEL FUSE SMT | -40°..+85° | FAE | SMD | FS-0603 | 40877
14 | 1 | J1 | NU | S2B-XH-A(LF)(SN) | CONN. XH 2P M/90° P=2.5 S2B-XH-A(LF)(SN) JST THT | | D-455-2257-ND | THT | J-2-0250-MOT-S2B
15 | 1 | J4 | NU | 0533980571 | CONN. PICOBLADE 5P M/D P=1.25 53398-0571 MOLEX SMT | | FAE | SMD | J-5-0125-MDS-PICOBLADE | 23467
16 | 1 | J8 | NU | 1051330001 | CONN. USB F/D TIPO MICRO-B C.S. 1051330001 MOLEX SMT | -30°..+85° | FAE | SMD | J-5-0065-FDS-UUSB1051330001 | 40807
17 | 2 | J9,J10 | NU | | STRIP 1P F/D P=2.54 H=7 NERA 801-87-036-1001 | | FAE | THT | J-8-0254-FDT | 1692
18 | 2 | J14,J16 | NU | 0733910060 | CONN. SMA F/D 50OHM 0733910060 MOLEX | | D-WM5543-ND | THT | J-FDT-SMA-73391
19 | 1 | L4 | NU | BLM21PG221SN1D | FILTRO 220R 2A 25% 0805 BLM21PG221SN1D MURATA SMT | -55°..+125° | FAE | SMD | LS-0805 | 20590
20 | 1 | L15 | NU | LQG15HS27NJ02D | INDUTTANZA 27nH 0.35A 5% 0402 LQG15HS27NJ02D MURATA SMT | -55°..+125° | FAE | SMD | LS-0402 | 42811
21 | 1 | Q11 | NU | | TRANSISTOR MOSFET P BSS84,215 SOT-23 SMT | -55°..+150° | FAE | SMD | SOT23 | 28241
22 | 1 | Q12 | NU | | TRANSISTOR NPN BC817-25 SOT-23 SMT | | FAE | SMD | SOT23 | 15414
23 | 26 | R4,R9,R11,R12,R35,R38,R61,R62,R78,R91,R110, R112,R117,R140,R142,R180,R190,R204,R218,R 222,R223,R228,R241,R244,R245,R246 | NU | | CHIP RES. 0R 0402 1/16W 1% | | FAE | SMD | RS-0402 | 25681
24 | 1 | R31 | NU | | CHIP RES. 1M 1206 1/4W 1% | | FAE | SMD | RS-1206 | 39104
25 | 12 | R32,R36,R39,R40,R41,R42,R43,R44,R45,R46,R4 7,R50 | NU | | CHIP RES. 33R 0402 1/16W 1% 100PPM/°C | | FAE | SMD | RS-0402 | 38764
26 | 4 | R33,R34,R48,R49 | NU | | CHIP RES. 0R 0603 1/16W 1% | -55°..+150° | FAE | SMD | RS-0603 | 15541
27 | 5 | R37,R57,R215,R240,R255 | NU | | CHIP RES. 100K 0402 1/16W 1% | | FAE | SMD | RS-0402 | 25127
28 | 2 | R51,R130 | NU | | CHIP RES. 1K 0402 1/16W 1% | -55°..+155° | FAE | SMD | RS-0402 | 25126
29 | 2 | R53,R54 | NU | | CHIP RES. 100R 0402 1/16W 1% | | FAE | SMD | RS-0402 | 26315
30 | 9 | R59,R60,R92,R93,R97,R214,R220,R221,R253 | NU | | CHIP RES. 10K 0402 1/16W 1% | -55°..+125° | FAE | SMD | RS-0402 | 25129
31 | 1 | R86 | NU | | CHIP RES. 5K6 0402 1/16W 1% | -55°..+155° | FAE | SMD | RS-0402 | 26324
32 | 2 | R106,R107 | NU | | CHIP RES. 0R 0805 1/8W 1% | | FAE | SMD | RS-0805 | 27410
33 | 1 | R191 | NU | | CHIP RES. 10R 0402 1/16W 1% 100PPM/°C | -55°..+125° | FAE | SMD | RS-0402 | 25130
34 | 1 | TVS6 | NU | | INTEGRATO ESDR0502NMUTBG ONSEMI UFDFN6 SMT | -40°..+125° | FAE | SMD | UFDFN6 | 40789
35 | 2 | TVS16,TVS17 | NU | PESD0402-140 | DIODO TVS BIDIR. 14V PESD0402-140 LITTELFUSE 0402 SMT | -55°..+125° | M-650-PESD0402-140 | SMD | RS-0402
36 | 1 | U1 | NU | TXS0104ERGYR | INTEGRATO TXS0104ERGYR TEXAS VQFN14 SMT | -40°C..85°C | FAE | SMD | VFQFN14-EXP-0350X0350 | 41323
37 | 1 | U2 | NU | TXS0108ERGYR | INTEGRATO TXS0108ERGYR TI VQFN20 SMT | -40°..85° | D-296-24806-1-ND | SMD | VFQFN20-EXP-0350X0450
38 | 1 | U13 | NU | LSM6DSO32 | INTEGRATO LSM6DSO32TR ST 14VFLGA SMT | -40..+85 | M-511-LSM6DSO32TR | SMD | VFLGA14L
CUSTOMER | MIT
PROJECT | 2022-0630 (CITYSCANNER-EVO)
REVISION | 3
SCHEMATIC | 20220630_CITYSCANNER-EVO_V3
DATA | 07/07/2023
DRAFTED | M. Brevi
APPROVED | Nome Approved

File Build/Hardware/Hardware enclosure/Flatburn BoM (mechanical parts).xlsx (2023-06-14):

Fabrication files | Description | Details | Footprint | Link to file
 | Core module front-portion | 3D printing (~10 hrs) | 168 x 195 mm | https://github.com/MIT-Senseable-City-Lab/OSCS/blob/main/Build/Hardware/Hardware%20enclosure/To%20Print/flatburn_core_module_front.stl
 | Core module back-portion | 3D printing (~10 hrs) | 170 x 195 mm | https://github.com/MIT-Senseable-City-Lab/OSCS/blob/main/Build/Hardware/Hardware%20enclosure/To%20Print/flatburn_core_module_back.stl
 | Sensor module | 3D printing (~7 hrs) | 128 x 204 mm | https://github.com/MIT-Senseable-City-Lab/OSCS/blob/main/Build/Hardware/Hardware%20enclosure/To%20Print/flatburn_sensor_module.stl
 | PCB clamps (left) | 3D printing (~1 hrs) | 130 x 18 mm | https://github.com/MIT-Senseable-City-Lab/OSCS/blob/main/Build/Hardware/Hardware%20enclosure/To%20Print/flatburn_pcb_clamp_left.stl
 | PCB clamp (right) | 3D printing (~1 hrs) |  | https://github.com/MIT-Senseable-City-Lab/OSCS/blob/main/Build/Hardware/Hardware%20enclosure/To%20Print/flatburn_pcb_clamp_right.stl
 | Legs (x2) | 3D printing (~4 hrs) | 85 x 50 mm | https://github.com/MIT-Senseable-City-Lab/OSCS/blob/main/Build/Hardware/Hardware%20enclosure/To%20Print/flatburn_leg.stl
 | Base plate | Lasercutting (~2 min) | 320 x 190 mm | https://github.com/MIT-Senseable-City-Lab/OSCS/tree/main/Build/Hardware/Hardware%20enclosure/To%20lasercut
 | In-between' plate | Lasercutting (~2 min), or 3D printing (~ 3 hrs) | 220 x 140 mm | https://github.com/MIT-Senseable-City-Lab/OSCS/tree/main/Build/Hardware/Hardware%20enclosure/To%20lasercut
Materials, components | Description | Details | Quantity/size | Cost, approx. (USD) | Link (US examples)
 | 3D printer filament | Spool of PLA / ABS / PETG | 0.5 | 12.5
 | M3 screws | M3 x 0.5 thread, 6 mm length | 14 | 3.36 | https://www.mcmaster.com/91292A111/
 | M3 screw-inserts | M3 x 0.5 thread, 4.3 mm length | 14 | 3.64 | https://www.mcmaster.com/94459A130/
 | 1/4 screw-inserts (for the magnets) | 1/4"-20 thread, 3/8" length | 2 | 5.5 | https://www.mcmaster.com/94459A380/
 | O-rings (for base plate and solar panel) | 2.3 - 2.6 mm thickness cord stock | 1500 mm | 3.89 | https://www.mcmaster.com/9864K25/
 | Acrylic plate (base plate) | 1/8 in thickness | 320 x 190 mm | 5.29 | https://www.mcmaster.com/8505K722-8505K122/
 | Acrylic plate ('in-between' plate) | 5/64 in thickness | 220 x 140 mm | 2.2 | https://www.mcmaster.com/8505K722-8505K122/
 | Magnets |  | 2 | 70 | https://rigwheels.com/product/magnetic-mount/
 |  |  |  | 106.37
Suggested tools | Soldering iron (for screw inserts)
 | 3D printer (e.g. Prusa i3 MK3, Ultimaker, Ender 3)
 | Laser-cutter (e.g. ~70W CO2 laser, 24 x 36" bed)
 | M3 hex-key/screwdriver
 | Knife/blade (for cleaning 3D prints, cutting o-ring stock)
 | Superglue (for gluing in o-ring)

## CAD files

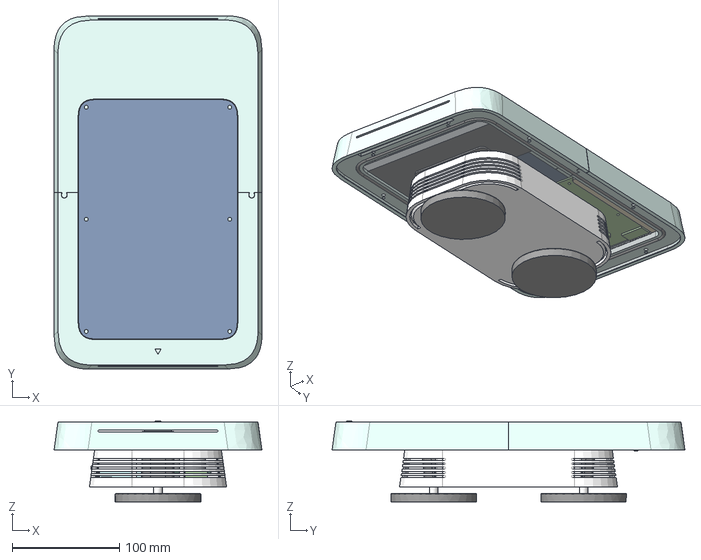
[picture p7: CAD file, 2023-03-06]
Build/Hardware/Hardware enclosure/Flatburn_assembly.step
194.2 x 329.6 x 75.3 mm

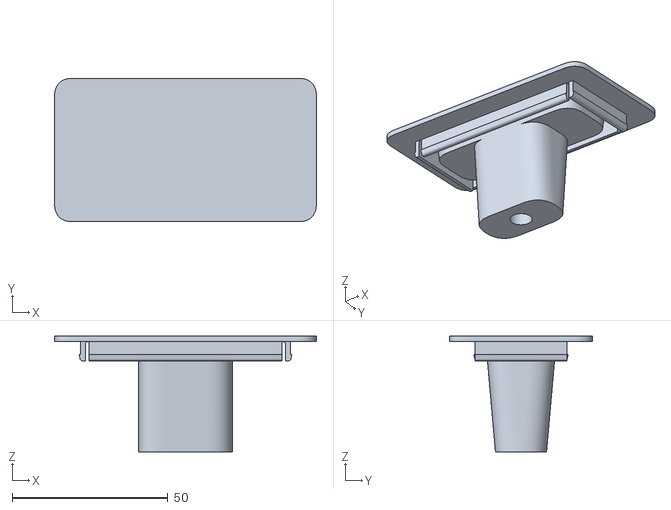
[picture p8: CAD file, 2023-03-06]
Build/Hardware/Hardware enclosure/To Print/flatburn_leg.stl
84.0 x 46.0 x 37.2

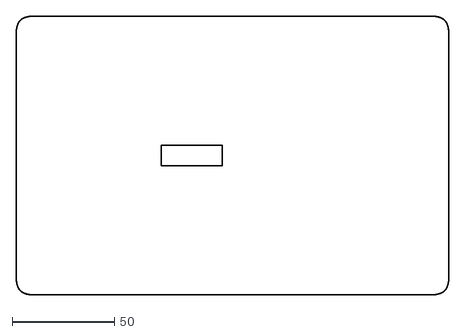
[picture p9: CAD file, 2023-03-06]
Build/Hardware/Hardware enclosure/To lasercut/flatburn_in-between_plate_5-64in.dxf
212.0 x 136.6

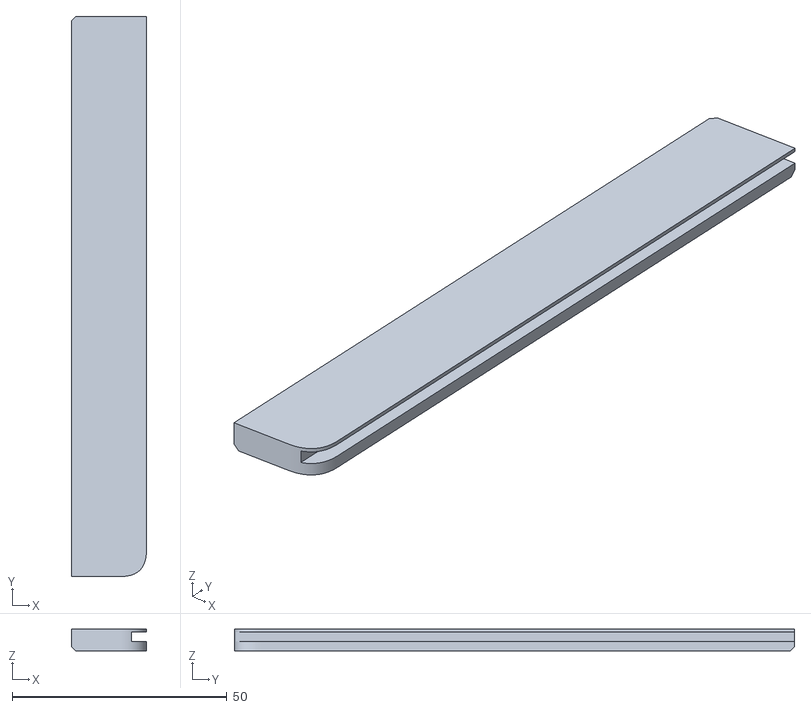
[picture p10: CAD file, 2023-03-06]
Build/Hardware/Hardware enclosure/To Print/flatburn_pcb_clamp_right.stl
17.4 x 130.5 x 5.11

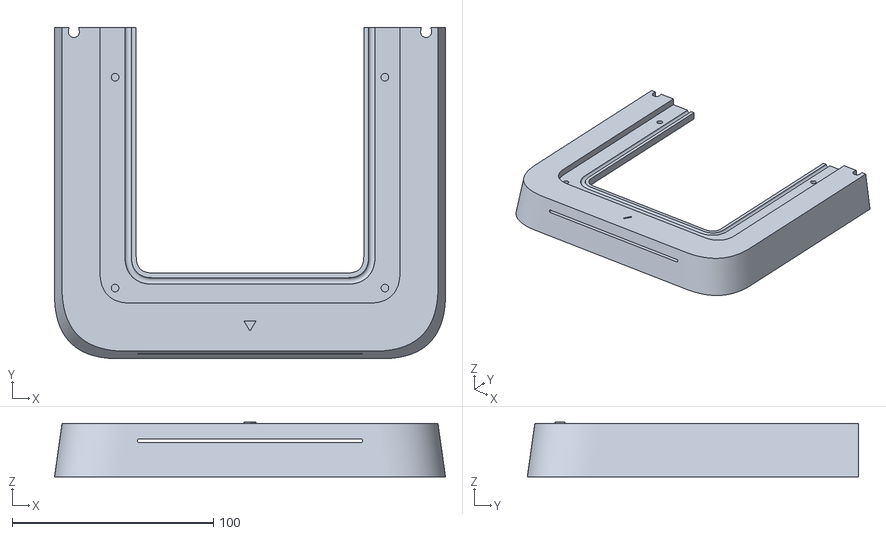
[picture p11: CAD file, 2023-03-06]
Build/Hardware/Hardware enclosure/To Print/flatburn_core_module_front.stl
194.2 x 164.6 x 27.1

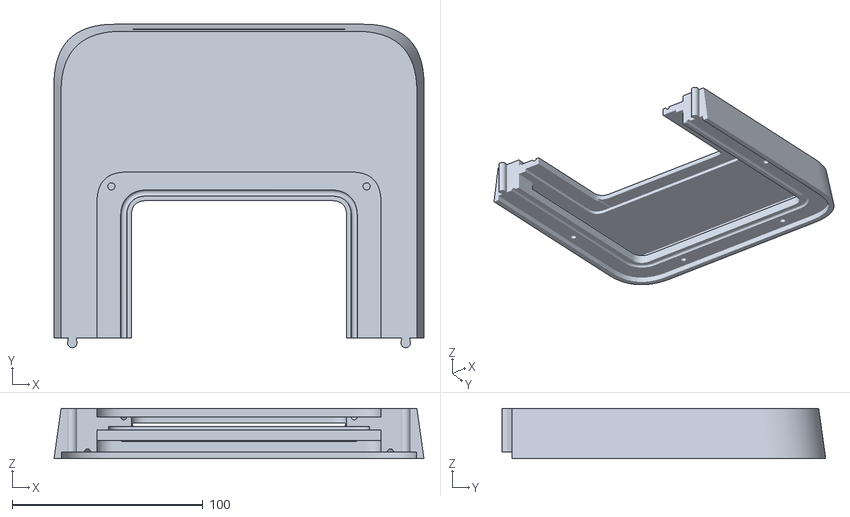
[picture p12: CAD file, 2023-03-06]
Build/Hardware/Hardware enclosure/To Print/flatburn_core_module_back.stl
194.2 x 169.8 x 26.5

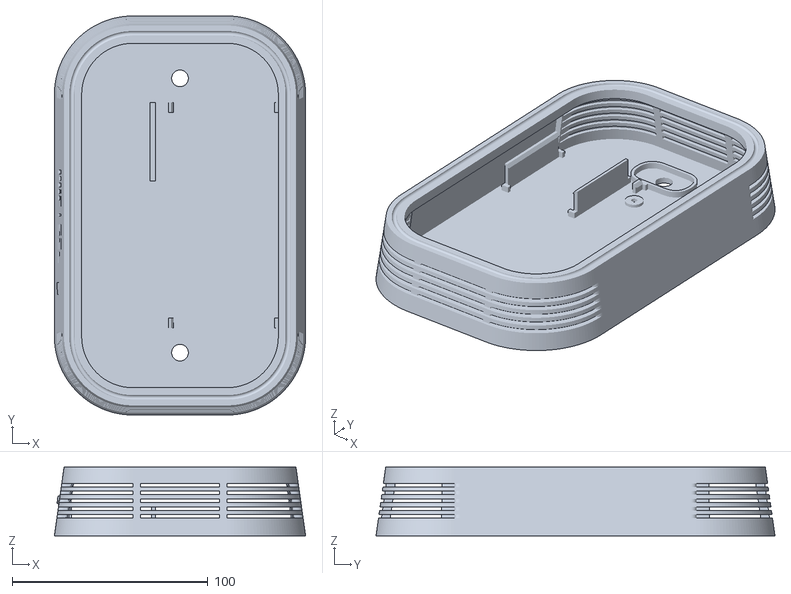
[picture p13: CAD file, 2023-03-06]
Build/Hardware/Hardware enclosure/To Print/flatburn_sensor_module.stl
128.2 x 203.6 x 35.0

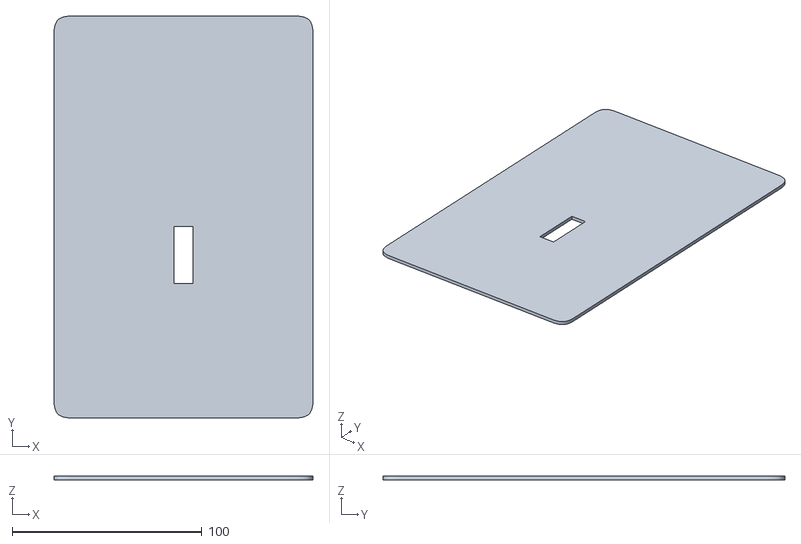
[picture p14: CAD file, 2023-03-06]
Build/Hardware/Hardware enclosure/To Print/flatburn_in-between_plate(if not lasercutting).stl
136.6 x 212.0 x 2.00

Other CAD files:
Build/Hardware/Hardware enclosure/To lasercut/flatburn_bottom_plate_1-8in.dwg
Build/Hardware/Hardware enclosure/To Print/flatburn_pcb_clamp_left.stl

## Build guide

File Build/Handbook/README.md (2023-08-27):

## Flatburn

# Assembly Guide

This assembly guide has step-by-step instructions on how to assemble a Flatburn. Look through the build section on our Github to gather all the required files for building the device. Follow the instructions in this guide (and feel free to customize the device and sensors as you see fit). We hope you have fun assembling your own Flatburn and collecting data about your environment!

# What you need to get started
- 3D printed and laser-cut parts,
- Fasteners and tools as specified in the [bill of materials](https://docs.google.com/spreadsheets/d/1-UVIJEneydIf8kLRng4QxvzjM4k2ZoDa/edit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)



# Assembly instructions
1. Slot together two halves of the core module

   

2. Use super-glue to secure the o-rings in the core module (solar-panel recess and base-plate recess) and to the top of the sensor module.

 



1. Using a soldering iron, add screw inserts to the core module and to the magnet-feet holders; small (M3) and large (¼ “) inserts respectively

  



2. Clip ‘in-between plate’ into core module. Feed solar panel cable through slot.

         

3. Screw solar panel onto the core module

  

4. Slide the main PCB into the back of the core module; secure with 3D printed clamps.

  

5. Slide battery into front of the core module

  

6. Connect solar panel and battery to the main PCB
   
  

7. Clip the magnet-feet holders into the base-plate
   


8. Feed the sensor-connector-cable through the slot in the base-plate and then secure the plate to the core module\



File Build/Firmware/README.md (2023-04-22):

# Flatburn Firmware

## Environment
- Code developed using [Particle.io plugin for MS Code](https://www.particle.io/workbench/)
- Devices can be flashed both via cable or cloud flash (data costs)
- Currently testing on bsom [Particle deviceOS@4.0.0](https://docs.particle.io/reference/device-os/firmware)
- Written in C++ and [Particle deviceOS APIs](https://docs.particle.io/reference/device-os/firmware/)

## Dev Environment Setup

1. Clone this repository
2. Open Particle Workbench
3. Run the `Particle: Import Project` command, follow the prompts, and wait for the project to load
4. Run the `Particle: Configure Workspace for Device` command and select a compatible Device OS version and the `bsom` platform when prompted ([docs](https://docs.particle.io/tutorials/developer-tools/workbench/#cloud-build-and-flash))
5. Connect your device
6. Compile & Flash!

## Quick overview of classes and files
- *cityscanner_config.h* main config file, needs to be updated before flashing
- *main.h* the program startpoint, should not be modified
- *cityscanner class* handles operation modes (more below)
- *CitySense class* manages data acquisition for environemental sensors (air quality, etc)
- *CityVitals class* acquires telemetry data (battery status, solar energy production, etc)
- *CityStore class* manages storing data on the SDcard, dumping data over TCP and over Particle Publish methods
- *MotionService class* used to send the device to sleep when the vehicle is not moving
- *LocationService class* provides gps data to other classes (e.g. CityStore)

## Operation modes
- *IDLE* sensors off, provides only telemetry data
- *REALTIME* logs data onto the SD card and send it in real time (via Particle publish)
- *LOGGING* buffer data onto the SD card and send multiple records upon request (via TCP)
- *PWRSAVE* like LOGGING but keeping the cellular modem OFF

#### Payload

deviceID, timestamp, latitude, longitude, PM1, PM25, PM10, bin0, bin1, bin2, bin3, bin4, bin5, bin6, bin7, bin8, bin9, bin10, bin11, bin12, bin13, bin14, bin15, bin16, bin17, bin18, bin19, bin20, bin21, bin22, bin23, flowrate, countglitch, laser_status, temperature_opc, humidity_opc, data_is_valid, temperature, humidity, ambient_IR, object_IR, gas_op1_w, gas_op1_r, gas_op2_w, gas_op2_r, noise

### Vitals
deviceID, timestamp, latitude, longitude, SOC_batt, temp_batt, voltage_batt, voltage_particle, current_batt, isCharging, isCharginS, isCharged, temp_int, hum_int, voltage_solar, current_solar, cell_strenght

# Command line interface
The CLI is available via REST, Particle.io Console and Slack. Each command might have 0-3 parameters. Some command return via Particle events or serial. *Commands are comma-separated* 

Command | Parameter #1 | Parameter #2 | Parameter #3 | Description
--------|--------------|--------------|--------------|-------------
battery |              |              |               | returns battery state_of_charge,temperature,voltage,voltage_alt,current,isCharging
solar   |              |              |               | returns solar panel voltage,current 
stop | || |Stops the device (light sleep) for 12hours or until it woken up by a motion even 
hibernate | [duration] | seconds OR minutes OR hours| Hibernate the device (heavy sleep)
reboot  | | | | Resets the device to default
location | | | | Returns the latest known GPS coordinates
device | check | | Return the device ID and last payload, useful for multiple devices
last | payload | | Return the last payload (See payload schema above)
last | vitals | |  Return the last vitals (See vitals schema above)
sd | files | | | Returns n. of files buffered in the SD card
sd | dump | all | | Dump all files queued on the SD to mongoDB via TCP
sd | dump | [files_number]] | | Dump the number of files passed as parameter to mongoDB via TCP
sd | format | | | Format SD card *DO NOT USE*
cellularOFF | | | | Turns off the cellular modem untill the device is manually powercycled 
autosleep | on | | | Device goes to sleep after x minutes of no montion
autosleep | off | | | 
heat-cool | on | | | Turns on the heater or the fan
heat-cool | off | | |

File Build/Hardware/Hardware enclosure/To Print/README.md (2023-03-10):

Exported `.stl` files for printing on a desktop 3D printer (e.g. Prusa i3 MK3, Ender 3, Ultimaker, etc). Use a slicer like [Cura](https://ultimaker.com/software/ultimaker-cura) to prepare `.gcode` files for the parameters of your printer.

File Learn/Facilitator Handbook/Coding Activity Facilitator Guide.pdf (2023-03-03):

### Coding Activity Facilitator Guide

jSchedule
- Lecture (up to 1 hour)
- Python activity + Discussion (up to 2 hours)
- Python notebook

Introductory Lecture
Please utilize the accompanying Introductory Lecture Slides for this activity. Python Activity Instructions

During the Workshop Introduction

- Ensure students have access to the notebook and relevant data files.
During the Workshop
- When the students run code block #13, which creates the first .html map, let them know that the .html file can be saved to their desktop.
- They will need to download the file onto their computers and then double click to open it in their web browser and interact with it.
- Please ensure they know which location they are saving the .html file to (eg, Desktop or Downloads folder).

Discussion prompts

- What do you think the biggest issues surrounding pollution hotspots in The Bronx are, versus where you are?
- Have you, your friends, family, or coworkers been affected by air pollution? What do you hope can be done about it?
- Share what you learned about different methods of environmental sensing.

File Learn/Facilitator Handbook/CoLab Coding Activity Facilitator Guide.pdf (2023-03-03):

### Coding Activity Facilitator Guide

jSchedule
- Lecture (up to 1 hour)
- Python activity + Discussion (up to 2 hours)
- Google CoLab notebook ”SAL Activity” provided in Google Drive

Introductory Lecture
Please utilize the accompanying Introductory Lecture Slides for this activity.

Python Activity Instructions
Before the Workshop
- Before the workshop begins, please send out an email to the organizers asking them to ensure that all participants have a Google GSuite account, are familiar with Google Drive, and have the Google CoLaboratory (CoLab) extension installed.
- The recommended browser for this workshop is Google Chrome.
- If participants do not have Google CoLab, they can do so with the following process:
1. Click the “New” button on the left hand side of the Google drive page.
2. Then scroll down to the “More” option from the popup menu.
3. Next, scroll down to the “Connect More Apps” option on the second pop up menu and click on it.
4. This should bring up the Google Workspace Marketplace.
5. Use the search bar to search for Colaboratory, and select the option that shows up.
6. Click the blue “Install” button, give the extension the necessary permissions, and you should be set up!

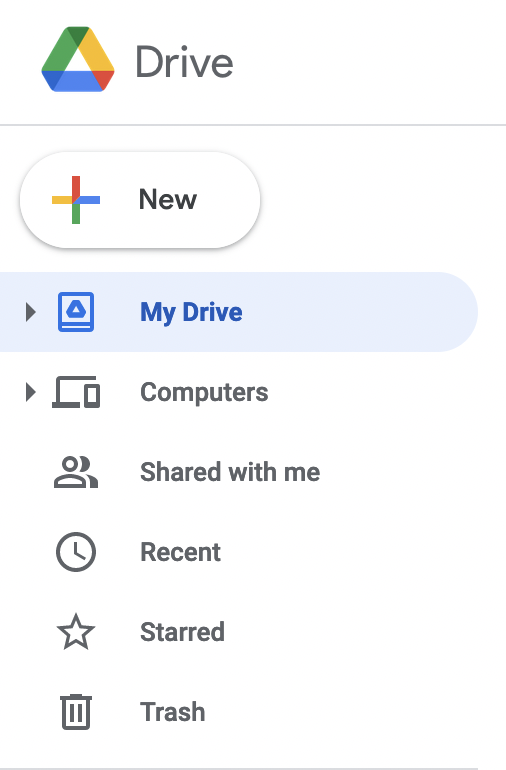
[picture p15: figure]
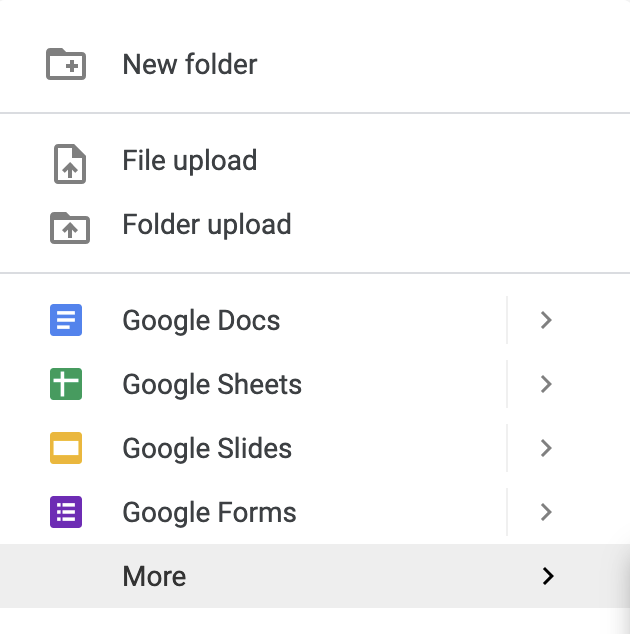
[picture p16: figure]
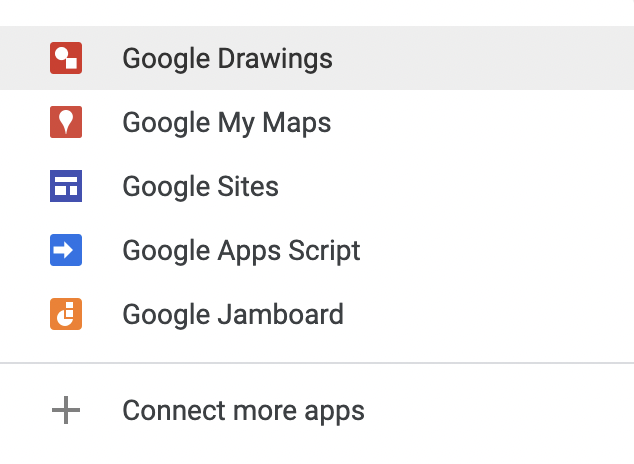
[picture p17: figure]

Step 1 | Step 2 | Step 3

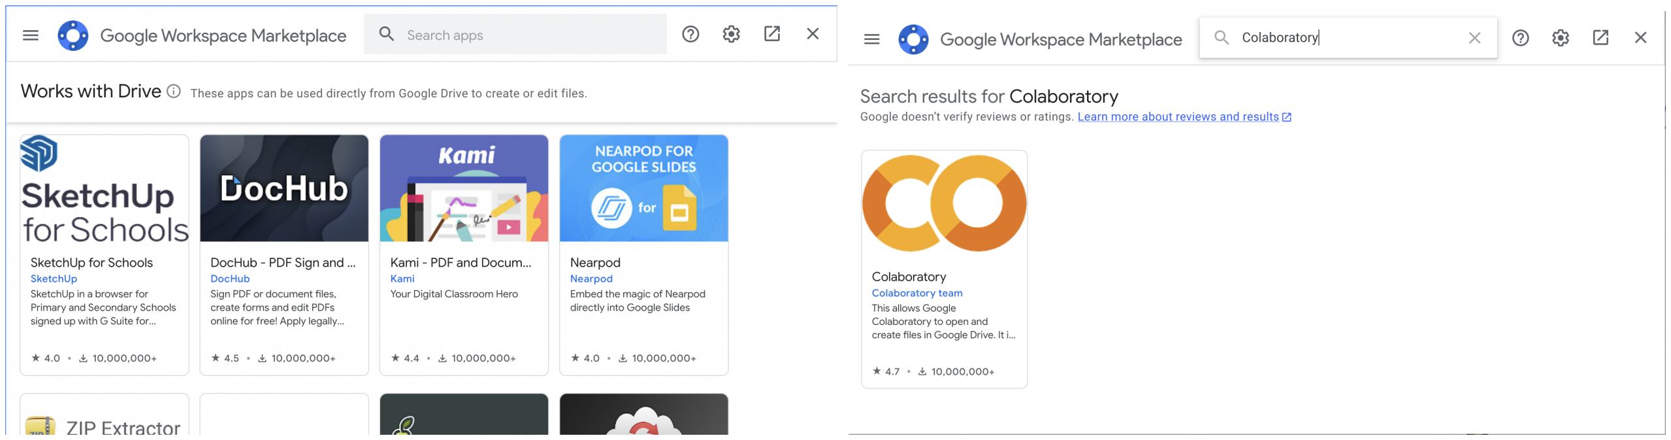
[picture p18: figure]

Step 4 Step 5

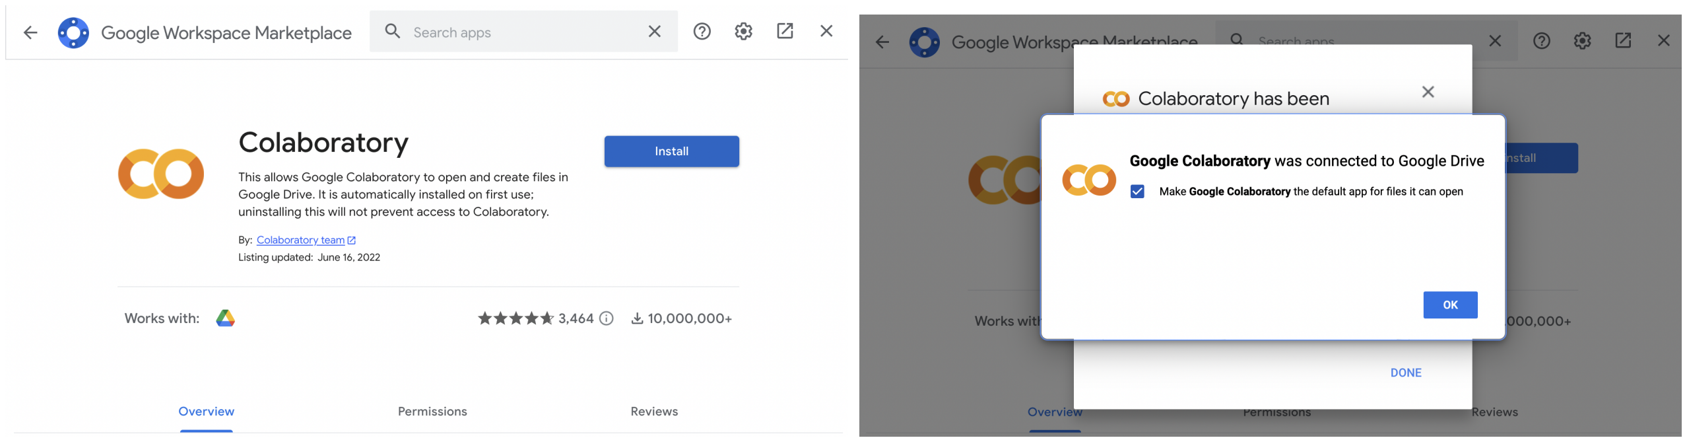
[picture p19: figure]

Step 6 Success!
- Participants should also be encouraged to explore the CoLab welcome site (https://colab.research.google.com/) prior to the workshop if they are not familiar with the platform.
During the Workshop Introduction
- Provide students with the link to the zip file containing the notebook and relevant data files:
- Ask the students to download the zip file onto their computer, and unzip the files.
- Then, ask them to upload the folder to their Google Drive and rename the folder “THEIRNAME_WorkshopName”. The path to get to the folder should be ‘/content/drive/My Drive/THEIRNAME_WorkshopName.
- Ask the students to modify the path in Block 4 to reflect this
During the Workshop
- When the students run code block #13, which creates the first .html map, let them know that the .html file will be saved in the Google Drive folder they created.
- They will need to download the file onto their computers and then double click to open it in their web browser and interact with it.
- Please ensure they know which location they are saving the .html file to (eg, Desktop or Downloads folder).

Discussion prompts

- What do you think the biggest issues surrounding pollution hotspots in The Bronx are, versus where you are?
- Have you, your friends, family, or coworkers been affected by air pollution? What do you hope can be done about it?
- Share what you learned about different methods of environmental sensing.

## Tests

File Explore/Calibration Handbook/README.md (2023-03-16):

In this folder, we present an open source [calibration manual](https://github.com/MIT-Senseable-City-Lab/OSCS/blob/main/Explore/Calibration%20Handbook/Calibration%20Handbook.pdf) to best assist our users in low-cost air sensor calibration, especially the use of City Scanner. We also provide [calibration codes](https://github.com/MIT-Senseable-City-Lab/OSCS/blob/main/Explore/Calibration%20Handbook/Calibration%20Code) that we used to demonstrate a standardized calibration process.

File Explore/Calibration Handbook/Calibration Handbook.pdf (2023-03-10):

### City Scanner In-Situ Calibration and Deployment: A Manual

An Wang
an_wang@mit.edu
Senseable City Lab, MIT

### 1 GETTING TO KNOW CITY SCANNER

### 1.1 Background

Mobile environment monitoring is a fast-developing method capable of providing high

spatial resolution information on air quality, noise, heat, and meteorology. It has been attracting

prominent attention from the scientific community and the public for a wide range of applications,

including tracing emission sources, evaluating ambient air pollution distribution, and estimating

personal exposures. The City Scanner project initiated by the Senseable City Lab at MIT is a

pioneer in mobile environment monitoring. It aims at developing a sensing platform to enable

large-scale environmental sensing tasks using existing urban fleets as sensing nodes. We envision

the platform to be adopted as a novel type of city infrastructure to enable big data collection and

evidence-based environmental/climate policymaking.

In general, City Scanner adopts a low-cost, modular design with internet-of-things (IoT)

capabilities. Environmental sensing can be expensive and high maintenance in the traditional

approach. United States Environmental Protection Agency (US EPA) defines that any air sensor

for single or multiple pollutants costing less than $2500 is considered low-cost. Sensors used on

the City Scanner are generally less than $500 and are tested with good accuracy and precision.

City Scanner implements a modular design for its on-board sensors to lower unit costs even more.

Users can easily keep redundant sensing modules to a minimum and adapt the platform in different

urban environment deployments. City Scanner is also IoT-enabled, where individual sensing units

are mounted on top of urban fleets for data collection and stream data to the cloud for storage,

manipulation, and analysis via a cellular network. Jointly, these designs have made City Scanner

a leading mobile sensing platform to empower environmental scientific research, support

evidence-based environmental and climate decision-making, and encourage citizen engagement

and awareness in environmental justice topics.

### 1.2 Sensing modules on a City Scanner

We illustrate City Scanner version ‘Flatburn’ that is being used for multiple data collection

campaigns in global cities in Figure 1. Each City Scanner has two major modules: the core and

sensor modules. The core module houses the motherboard, the data communication and local

storage system, and the battery and thermal performance management system. The sensor module,

GPS and solar panel are connected to and managed by the core module. The core module design

detailsre presented in the hardware and firmware open-source manual. (https://github.com/MIT-Senseable-City-Lab/OSCS/blob/main/Build/Handbook/Flatburn_%20assembly%20guide.pdf) Here, we focus on the

sensor module that includes all environmental sensors. Figure 1 demonstrates the anatomy of a

baseline sensor module configuration. It contains one optical particle counter, two gas sensors, a

temperature and humidity sensor, and a noise sensor.

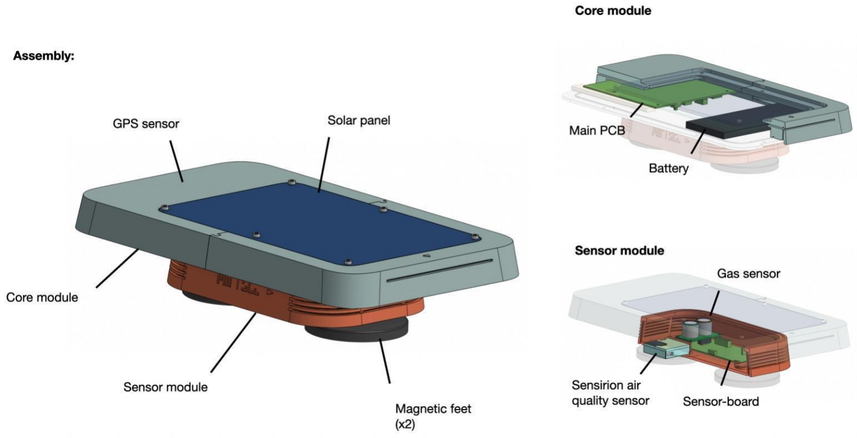
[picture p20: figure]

Figure 1. Flatburn basic configuration

We list the environmental sensors that are currently being used in Table 1. Sensirion SPS30

optical particle counter (OPC) is a low-cost sensor for measuring ambient particulate matter (PM).

A laser beam is emitted through the air flow being drawn in so that by counting the pulses of light

scattered by particles in the air flow, OPC can count the number of particles. Based on the intensity

of scatter light, it is also able to measure particle size. Sensirion OPC has been adopted in academic

and citizen science projects, whose performance and durability have been proven among other competitors in the market. Two gas sensors can be hosted in the sensor module at the same time.

Currently, we are using Alphasense’s electrochemical gas sensors for CO, NO2, and SO2. The

surface material on an electrochemical gas sensor reacts with the target gaseous pollutant, which

results in an electric current that passes from the working to the reference electrode. The current

is measured and is proportionate to the target pollutant’s concentration. The sensor board can also

be equipped with low-cost noise, temperature, and humidity sensors for measurements. But this

document mainly explained how air quality sensors are calibrated.

Table 1. Environmental sensor specifications

Sensor | Sensing object | Unit cost | Substitution
Sensirion SPS30 Optical Particle Counter | Particulate matter count and estimated mass concentration | $50 | With a thermal camera
Alphasense CO-A4 | Carbon monoxide | $50 | With other gas sensors
Alphasense NO2-A4 | Nitrogen dioxide | $50 | With other gas sensors
Alphasense SO2-A4 | Sulfur dioxide | $50 | With other gas sensors
MIC MEMS Analog | Noise | $0.88 | N/A
BME280 | Temperature, humidity | $7.28 | N/A

### 2 LOW-COST SENSOR CALIBRATION BASICS

### 2.1 The importance of calibration

Low-cost sensors suffer from constant data quality and stability issues. For example, the

abovementioned OPC cannot discern particulate matter from water droplets, thus, does not

function well in high-humidity environments. Moreover, OPC-observed PM mass concentration

is estimated based on particle shape and density assumptions, varying drastically from place to

place and season to season. Electrochemical gas sensors are known for their cross-sensitivity,

which is a common phenomenon where the electrochemical surface material reacts with gases

other than the target one. Therefore, sensor collocation and calibration are of utmost importance

to ensure accurate results before field deployment. Collocation is the process of deploying sensors

side-by-side with reference monitors and calibration involves adjusting raw sensor readings using collocation data and mathematical methods. We summarized seven issues that affect low-cost

sensor performance from low-cost sensor calibration literature within the last five years: inter-

sensor variability, intra-sensor variability, drift, aging, response time, cross-sensitivity, and

sensitivity to environmental factors.

Inter-sensor variability refers to the variability in measurements using multiple identical

sensors under the same testing environment. The calibration for inter-sensor variability is crucial

for low-cost sensors as it is the foundation of large-scale sensor deployment and data transferability.

Intra-sensor variability describes the variability in consecutive measurements a given sensor makes

under the same testing environment. Drift is the gradual change in sensor response over time.

Aging refers to the continuous deterioration of sensor performance over time. Unlike reference

sensors, low-cost sensors are prone to drifting and have a much shorter lifetime. Thus, they require

routine sensor calibration and replacement. Response time reflects the lag before sensors reach

stable readings in the test environment. The difference between response time and temporal signal

change scale is critical for time-resolved sampling. Cross-sensitivity, an issue exclusive to gas

sensors, denotes a sensor’s false response to gases other than the target gas. Finally, sensitivity to

environmental factors, including temperature, humidity, wind, barometric pressure, and particle

composition, is ubiquitous in both low-cost and reference sensors. These environmental factors

are commonly identified as the main explanatory variables in low-cost sensor calibration models.

### 2.2 How do people calibrate sensors

The United States Environmental Protection Agency (EPA) is a federal agency that

regulates and manages environmental protection matters. They also provide references, guidelines,

and regulations considered “the gold standard” for air quality monitoring, primarily in the US and

many other countries. In order to facilitate the use of low-cost sensors for non-regulatory purposes,

EPA has initiated multiple projects and gathered opinions from various stakeholders. In 2021, EPA

published air sensor performance target reports for Ozone and PM2.5 low-cost sensors, which

provides consistent testing protocols, metrics, and target values to evaluate the performance of

low-cost sensors for non-regulatory applications. Previously, only a few studies followed regulated

sensor calibration protocols, whereas most studies developed their own project-specific protocols.

It hinders the inter-project comparison of low-cost sensors. Therefore, City Scanner’s calibration

and collocation protocols are mainly developed in conformity with the two reports published by

US EPA. In general, there are three phases of low-cost sensor calibration. The first phase is

collocation, which indicates a process of deploying low-cost sensors next to reference-grade

monitors. Reference monitors are a category of air sensors whose manufacturers, data quality, and

durability are certified by government agencies, specifically, EPA in the US. They are considered

the gold standard for air pollution monitoring in many regions across the globe. The second phase

is calibration, which includes adjusting raw low-cost sensor readings using statistical methods with

reference monitor data as the target variable. The last phase is evaluation, where the calibrated

results are tested against external reference monitor data (data not used in calibration training) with

statistical measures, such as Pearson correlation coefficient and mean absolute percentage error.

The three phases are detailed in Section 3.

### 3 CALIBRATING A CITY SCANNER

### 3.1 In-situ collocation setup

US EPA provides two standardized performance test protocols. The base testing involves

evaluating sensors in an outdoor environment, and the enhanced testing refers to the evaluation in

a controlled lab environment. Enhanced testing is recommended if a laboratory chamber is

available but not mandatory. Hence, we will focus on the base testing protocols in the City Scanner

context.

City Scanners are recommended to be collocated and calibrated in an environment that is

as similar to the deployment environment as possible. That is to say, City Scanners should be

calibrated locally at a reference air quality station if it is available and ideally in the same season

as the deployment. Considering sensor aging and drifting, if a deployment is more than six months

in length, it is highly suggested to have collocation before and after the deployment. Usually, City

Scanners are collocated at a reference station for at least two weeks for a single deployment. This

would generate over 300 paired hourly readings, which is sufficient to fit a simple multivariate

linear regression, but not enough to account for potential nonlinearity between low-cost sensor

response and meteorological factors using machine learning algorithms. It is suggested to have a

one-month consecutive collocation if time and space allow or require higher temporal resolution

reference monitor data (finer than hourly).

Figure 2 illustrates two previous collocation and calibration campaigns in New York City

(NYC) and Boston. The setup in NYC is more desirable. As we can see, five City Scanners are

placed next to each other, facing the same direction with a secure connection to a power source.

All are very close to the reference monitors’ air inlet. This is important to ensure consistent and

continuous monitoring. The reference station is located on the rooftop of a primary school. City

Scanners are elevated from the roof, and set securely on a flat platform with no obstruction around

them. This ensures free air flow from all directions and minimizes the effects of wake dust. The

setup in Boston is not ideal but can still yield valid results. The City Scanners are placed close to

the ground instead of the reference monitors’ inlet on the roof of the container in the back, as the

power socket is located on the ground. Moreover, our City Scanners are placed quite close to the

container that hosts various reference monitors, which induces the risk of not capturing pollutant

plumes from certain directions.

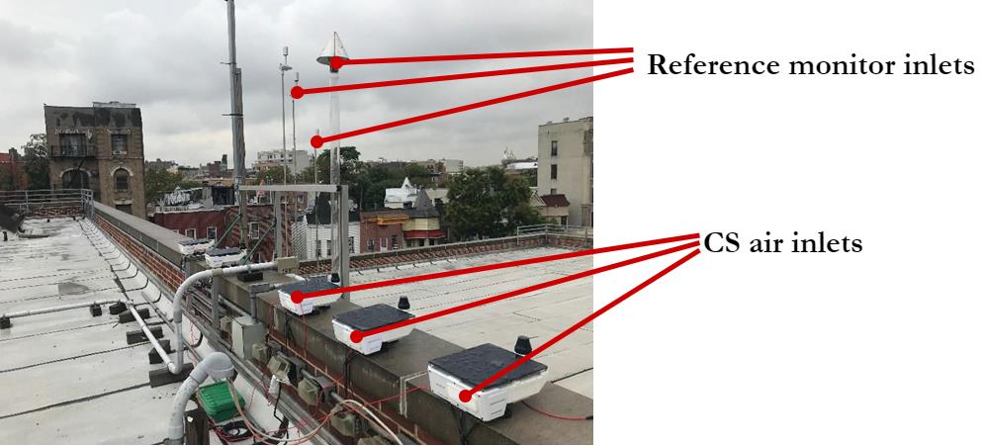
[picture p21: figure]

(a)

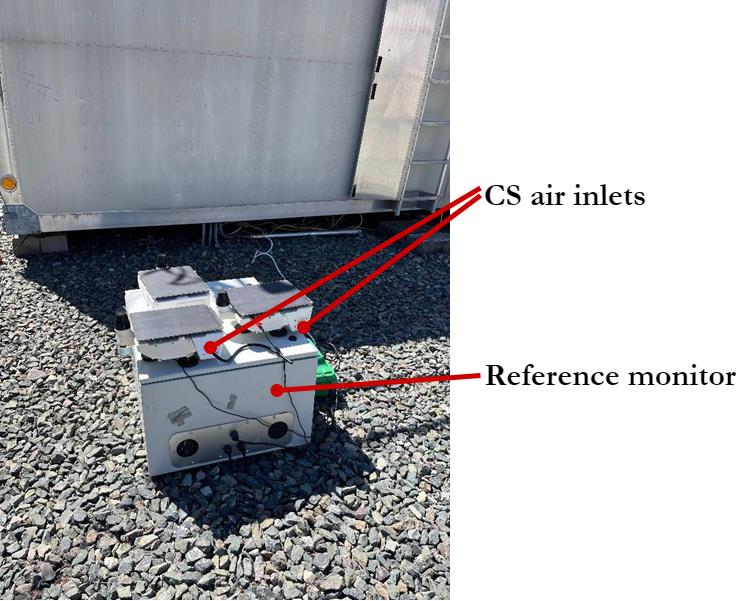
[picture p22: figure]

(b)

Figure 2. City Scanner collocation setup in (a) NYC (b) Boston

### 3.2 Data processing and digest

Collected data can be downloaded directly from the SD card located in the core module.

Locally downloaded data are not cleaned and do not have field names attached, which need to be

done manually in this case. Figure 4 presents a sample of locally downloaded raw data. Raw data

are separated into multiple files for a single deployment. There are three steps before one can use

it for calibration or analysis, including combining, filtering, and renaming. First, we need to

combine the data files from the same City Scanner in the same campaign. Second, the records

marked with ‘0’ in the first column are invalid and should be filtered out. Lastly, the first column

needs to be discarded so that all field names can be attached to each column. There are, in total,

46 fields as listed in Table 2. We have provided a simple python script (https://github.com/MIT-Senseable-City-Lab/OSCS/blob/main/Explore/Datasets/csparse_data.py) to automate this process.

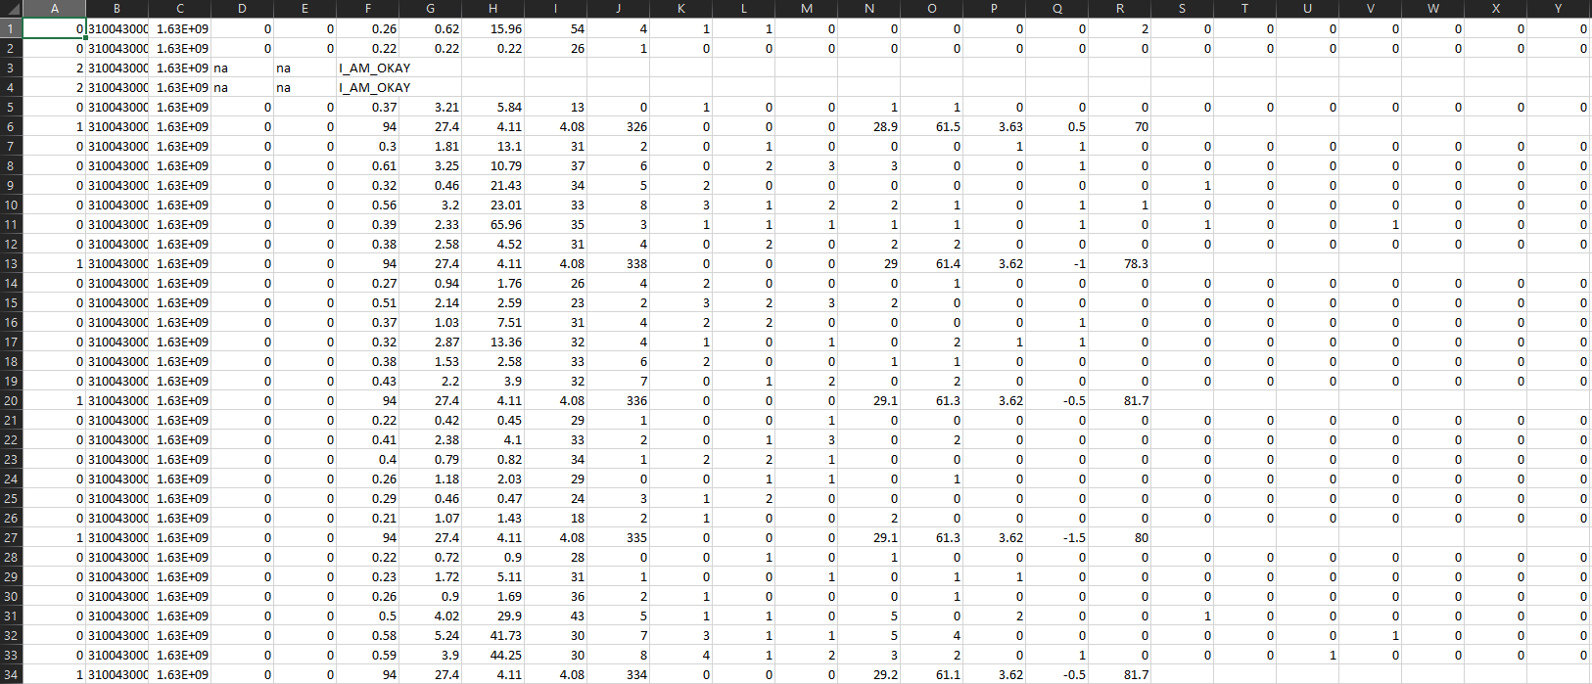
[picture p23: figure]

Figure 4. Locally downloaded City Scanner raw data from the previous City Scanner prototype

Table 2. City Scanner data file fields and definitions

Field name | Definition
deviceID | -
timestamp | Time stamp in epoch time
latitude | -
longitude | -
PM1 | PM1 mass concentration in ug/m3
PM25 | PM2.5 mass concentration in ug/m3
PM10 | PM10 mass concentration in ug/m3
flowrate | OPC flowrate at air inlet
countglitch | Possible OPC count errors
laser_status | OPC laser status
temperature_opc | OPC temperature in Celsius
humidity_opc | OPC humidity in percentage
data_is_valid | If OPC data is valid
temperature | Ambient temperature in Celsius
humidity | Ambient humidity in percentage

gas_op1_w | Gas sensor 1 working electrode millivoltage (This is the measurement proportionate to gas 1 concentration)
gas_op1_r | Gas sensor 1 reference electrode millivoltage
gas_op2_w | Gas sensor 2 working electrode millivoltage (This is the measurement proportionate to gas 2 concentration)
gas_op2_r | Gas sensor 2 reference electrode millivoltage
noise | Noise level in dB

Cleaned City Scanner data requires calibration against the reference monitor readings,

using meteorological factors as explanatory variables. Previously, we used meteorological factors

from a central weather station for all City Scanners circulating in a city, and the calibration

performance was satisfactory. Here, we mainly consider four factors that have effects on sensor

performance based on a previous City Scanner study, namely, temperature, humidity, air pressure,

and dew point. A conceptual calibration function is presented as follows, which can be fitted with

multivariate linear regression, but preferably an algorithm that can interpret nonlinearity, such as

random forest or gradient boosting trees. It is worth noting that we need to log-transform the

reference and City Scanner observations (pollutant concentration) to comply with the normal

distribution assumption if needed.

log (ref observation) = f(log (CS observation) ,temp, ℎumd, pres, dewp)

We have provided some sample codes to demonstrate the calibration process. The sample

codes take in synchronized reference air quality observations, City Scanner raw readings,

temperature, humidity, air pressure and dew point values that are aggregated to 1 min, 5 min, 10

min, 30 min, or 60 min intervals, which are common temporal resolution one can get from local

weather station and reference air quality monitors. Then, log-transformed City Scanner raw

readings and meteorological factors (in total,five predictors as in the previous equation) are passed

to a variety of calibration algorithms to train the best calibration model for each City Scanner unit.

The choice of the best calibration model is made by comparing the performance metrics in Section

3.3.

### 3.3 Performance metrics and quality assurance

Table 3 lists a series of performance metrics for base testing. It is compiled assuming

multivariate linear regression as the calibration algorithm. In reality, meteorological factors have

complex interactions with each other and with low-cost sensor performance. It is recommended

that other than linear regression, random forest calibration should be tested, which is a simple

machine learning model that can account for nonlinearity. As a rule of thumb, at least 500 data

points are needed to develop a robust random forest model.

Table 3. Performance metrics for base testing

Test type | Metric | Description
| | concurrently by three or more sensors of the same type collocated under the same sampling conditions. Precision is measured here using the standard deviation (SD) and coefficient of variation (CV).
| Bias | The systematic (non-random) or persistent disagreement between the concentrations reported by the sensor and reference instruments. Bias is determined here using the linear regression slope and intercept.
| Linearity (Important) | A measure of the extent to which the measurements reported by a sensor can explain the concentrations reported by the reference instrument. Linearity is determined using the coefficient of determination (Pearson correlation). As a rule of thumb, Pearson correlation should be over 0.9 after calibration.
| Error (Important) | A measure of the disagreement between the pollutant concentrations reported by the sensor and the reference instrument. Error is usually measured using the root mean square error (RMSE) or mean absolute percentage error (MAPE). As a rule of thumb, MAPE should be less than 15%.
| Exploring meteorological effects | A graphical exploration to look for a positive or negative measurement response caused by variations in ambient temperature, relative humidity, or dew point, and not by changes in the concentration of the target pollutant.
Base testing | Precision | Variation around the mean of a set of measurements reported

### 4 SUMMARY

This manual briefly introduced the background of the City Scanner project. It discussed in

detail a City Scanner’s sensor module, which includes environmental sensors for air quality, noise

and meteorology. We summarize several takeaways for collocation setup, including collocating

City Scanner in a similar environment as deployment, placing City Scanner close to the reference monitor’s air inlet, locating City Scanner on an elevated, secure platform with no obstruction

around it, and securing the power supply for continuous measurements. The manual also

introduces data quality assurance and post-processing in preparation for City Scanner calibration.

Data sources and algorithms for calibration are presented, recommending taking nonlinearity into

account in this process. A list of sensor performance measures is also provided.

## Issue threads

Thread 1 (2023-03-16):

BOM Missing Air Quality Sensor?

MCDELTAT, 2023-03-16:
I was having a look at the construction and BOM to see if this project would help me. I don't currently see any Air Quality sensors listed in the BOM here https://docs.google.com/spreadsheets/d/1-fR-0hTxHKbjaRf8DbH62WgUFVeNE4eUEsaAd-YdDYg/edit#gid=2089068555

At the moment you have:
1. MXC6655XA - Accelerometer
2. LSM6DSO32TR - Accelerometer, Gyroscope, Temperature, 6 Axis Sensor
3. SHTC3 - Temp/Rel Humidity

Is there something missing? Thanks.

internetoftobi, 2023-03-16:
Thank you for reaching out, if you click on the next tab label [AQ Ext. Board (Sensor board) ](https://docs.google.com/spreadsheets/d/1-fR-0hTxHKbjaRf8DbH62WgUFVeNE4eUEsaAd-YdDYg/edit#gid=1715502618)you will find the Air Quality sensor.

Thanks

Closed 2023-03-16.

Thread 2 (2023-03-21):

.brd file

rufnubbins, 2023-03-21:
Most of the PCB printers don't allow .brd files. While we can view the file in the free viewer, we cannot export. Any chance you'd be willing to provide a gerber file that can be submitted for printing without having to purchase a ($1500/mo) license for Allegro?

mayessaki, 2023-05-02:
On Autodesk Eagle, the .brd file can't open because it's missing the .sch file. Can you please provide it?

IlseOvervelde, 2024-03-11:
We are running into the same problem, any chance there are updates on this?

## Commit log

2023-03-03 Create Fabrication files - Hardware schematics
2023-03-03 Hardware schematics
2023-03-03 PCB layout
    PCB design
    [Flatburn-sensor-board PCB.brd]
2023-03-03 Create calibration
2023-03-03 Create calibration code
2023-03-06 Assembly file
    [Flatburn_assembly.step]
2023-03-06 Create print
2023-03-06 3D files
    [flatburn_core_module_back.stl, flatburn_core_module_front.stl, flatburn_in-between_plate(if not lasercutting).stl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]
2023-03-06 Create laser cut
2023-03-06 Lasercut files
    [flatburn_bottom_plate_1-8in.dxf, flatburn_in-between_plate_5-64in.dxf]
2023-03-06 BOM (Bill of Materials)
    [Flatburn hardware components.xlsx]
2023-03-08 Delete mechanical parts _ Flatburn.xlsx
    needs to be updated
    [mechanical parts _ Flatburn.xlsx]
2023-03-10 Silkscreen design
2023-03-10 Rename Explore/Datasets/Bronx_lurtrain.py to Explore/Calibration codes/Bronx_lurtrain.py
2023-03-10 Rename Explore/Datasets/Master_Calibration.py to Explore/Calibration codes/Master_Calibration.py
2023-03-10 Rename Explore/Datasets/boston_calibration.py to Explore/Calibration codes/boston_calibration.py
2023-03-10 Rename Explore/Datasets/csparse_data.py to Explore/Calibration codes/csparse_data.py
2023-03-10 Rename Explore/Datasets/nyclu_extract.py to Explore/Calibration codes/nyclu_extract.py
2023-03-12 renamed calibration handbook
2023-03-12 Added BoM link
2023-03-13 Add sensor libraries
2023-03-13 Photos - main assembly steps of the prototype
2023-03-13 Added image showing main assembly steps
    Prototype assembly in February
2023-03-15 Update Assembly_Guide
2023-04-18 Accelerometer lib for kxtj3
2023-04-18 Pin mapping
2023-04-18 Changed the battery_volatage pin
2023-04-18 ADC lib for alphasense afe gas sensor
2023-04-18 added kxtj3 acc sensor
2023-04-18 motion sensor modification
2023-04-18 Added SHTC3 sensor
2023-04-19 SEN55 OPC sensor
2023-04-22 Added a new CLI to return device status
2023-04-22 use device-check to get it updated on dashboard
2023-06-14 Added BoM Excel sheet
    [Flatburn BoM (mechanical parts).xlsx]
2023-06-14 updated link to mechanical BOM
2023-07-14 added 3d printer settings
2023-08-03 updated link to new hw bom
2023-08-03 updated main board sch,brd,bom to V2
2023-08-03 updated bottom plate to fit the new v2 hw
    [flatburn_bottom_plate_1-8in.dwg, flatburn_bottom_plate_1-8in.dxf]
2023-08-04 updated sensor board sch,brd to V2, added BOM
    [Flatburn-sensor-board PCB.brd, Flatburn-sensor-board-PCB.brd]
2023-08-24 Create Flatburn_ Assembly_ Guide.md
    Flatburn Guide
2023-08-24 Assembly Instructions 1 and 2
2023-08-24 o-ring with glue pictures
2023-08-24 using soldering iron
